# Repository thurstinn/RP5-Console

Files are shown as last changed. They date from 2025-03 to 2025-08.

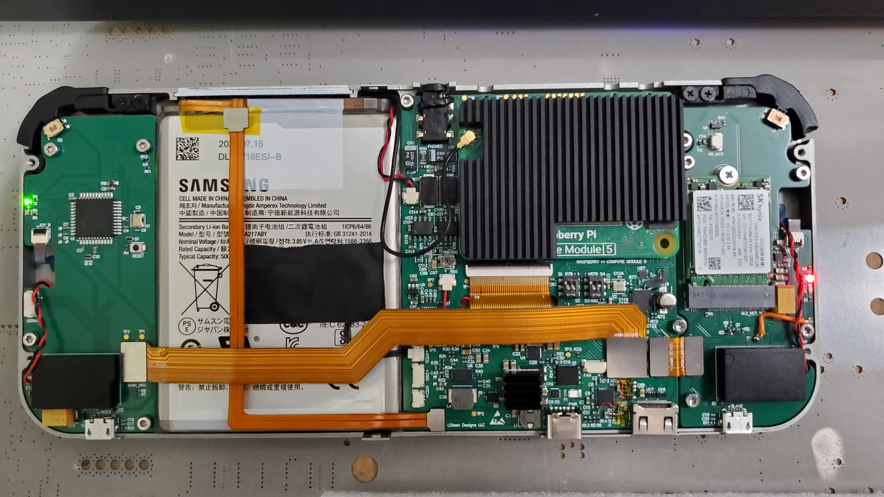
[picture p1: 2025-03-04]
Images/Internal.jpg

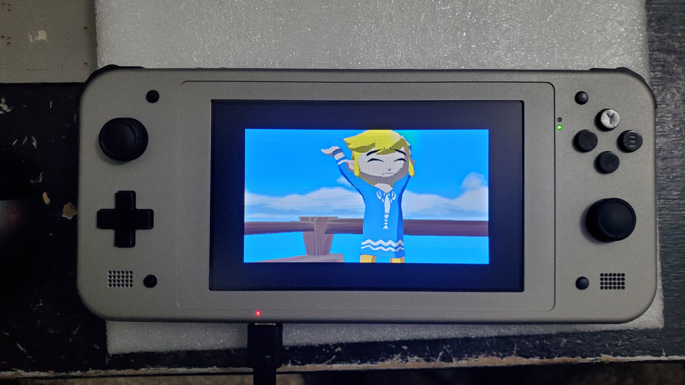
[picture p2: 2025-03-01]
Images/Front2.jpg

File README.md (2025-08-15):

# RP5-Console



This project was inspired by StonedEdge's impressive Retro-Lite-CM4 https://github.com/StonedEdge/Retro-Lite-CM4. I do not use any of their files directly (the exception being their project partner's Ardupad.ino https://github.com/dmcke5/Ardupad), but some of the design choices were influenced by their console.

The process of building this console and setting it up can be complex, expensive, and time consuming. Not for the faint of heart

Assuming you have all the boards assembled and all the parts ready, assembly is pretty straightforward. Use the images as a guide. You will have to extend the speaker wires to reach their connectors. DO NOT GLUE THE BATTERY OR ANYTHING TO THE BACK OF THE SCREEN! I use a large square piece of soft foam double sided taped to the inside of the back cover to compress down on the battery, and by extension the screen, to hold it in place. Tape could also be used. I also chose not to glue or use double sided tape to keep the screen attached to the front cover. I use kapton tape on the outer edges of the screen. Kapton is clean and holds well after compressing it down on a surface. I also used 3mm thick harder foam pieces attched at various points on the back of the main board to softly compress against the back of the screen. This is in an effort to make replacing parts much easier while avoiding damage.

# Setup

Keep battery installed but disconnected until prompted

With the back casing removed and the battery disconnected, place console face down on a soft surface

Set manual power switch to on position (Use dull-ended tweezers)

ATSAMD21E18A and ATMEGA32U4 ICs need USB bootloaders. ATMEGAs Leonardo bootloader can be acquired and flashed using an Arduino Nano in Arduino IDE. ATSAMD21s Adafruit Trinket M0 bootloader can be flashed using a J-Link EDU mini in Microchip Studio. There are online resources for help with this (https://learn.adafruit.com/how-to-program-samd-bootloaders/overview). (I couldn't get Microchip Studio to read the chip on my Windows 11 desktop but it worked on my Windows 10 laptop) You will need to make wire breakouts from the associated connectors for each device. The MPN for the mates of each connector are located in the schematics (SUHR-0XV-S). The MPN of the metal contacts that need crimped on the wires (32-28 awg) for all connector mates is: SSUH-003T-P0.15

Connect the battery

Connect Raspberry Pi 27W USB-C Power Supply (or any USB-C Power Delivery 12V 2A+ capable supply) to USB-C port on the console

Burn the bootloaders

Press the reset buttons on each device

Connect a Micro-USB cable from the slave port (right Micro-USB port with console face down) to PC

Follow the truth table on the Main Board/USB schematic for ATSAMD21 (Switch 1-4 = low, high, low, high) and ATMEGA (Switch 1-4 = high, low, low, high) (low = switch down position and vice-versa)

Use Arduino IDE to flash the included scripts for each device. For ATSAMD21, install and select Adafruit Trinket M0 and double-click reset button to show up as COM Port. For ATMEGA, select Arduino Leonardo and hit the reset button once flashing begins

Follow the instructions in the Ardupad script to calibrate the joysticks

Follow the instructions in the README in the EDID folder

Set manual power switch to off postition

If using an SSD or EMMC, follow the truth table on the Main Board/USB schematic to boot CM5 in rpiboot mode: (Switch 1-4 = low, low, high, low)

Set manual power switch to on position

On PC, install and run Raspberry Pi Imager: https://www.raspberrypi.com/software/

On PC, follow the instructions to install and run rpiboot for CM5 at: https://www.raspberrypi.com/documentation/computers/compute-module.html#set-up-the-host-device

Follow the instructions to install retropie on PI5 OS Lite at: https://github.com/danielfreer/raspberrypi5-retropie-setup (Choose SSD if installed or EMMC as storage unless you have CM5 Lite version. In that case, skip rpiboot and just flash an SD Card)

Set manual power switch to off postition

Follow the truth table on the Main Board/USB schematic for normal operation: (Switch 1-4 = low, low, low, high)

Turn the trimming resistor (R68) just over half way. If turned much more it could damage the speakers

Set manual power switch to on postition and keep it there

Use WinSCP or SSH Terminal to:

Make sure /boot/firmware/config.txt is identical to included config.txt file

Copy Scripts folder to /home/pi/

In SSH Terminal:

Copy service file contents for each file to new files of the same names in /etc/systemd/system/ ex: sudo nano /etc/systemd/system/fan.service

Enable each service: ex: sudo systemctl enable fan.service

Run:

sudo apt remove python3-rpi.gpio

sudo apt-get install python3-rpi-lgpio

sudo apt-get install python3-evdev

sudo nano /var/log/fan.log (write out empty file)

sudo nano /var/log/fan.rpm (write out empty file)

sudo chmod 777 /var/log/fan.log

sudo chmod 777 /var/log/fan.rpm

In (sudo raspi-config) and retropie/audio, set the audio output to USB AUDIO CODEC

In the retropie main menu/sound settings (press start button), the audio card should be default and device should be PCM

sudo reboot

To turn on the console, press and hold the power button for 5 seconds. The power led will turn on (red) and then switch to the activity led (now solid green). To turn off, press and hold the power button for 5 seconds. This will soft shutdown the OS and then turn off the console. If you shutdown the OS via the UI or terminal, you will have to press and hold the power button once the shutdown process has finished to turn off the console

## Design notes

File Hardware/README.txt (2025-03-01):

Files named with Right/Left designate which parts are Right/Left with the console laying facedown, 
as would be during assembly. This was done because while designing I visualized the system this way,
and so I named the parts accordingly to avoid a mix-up. So right is actually left when the console is
facing you like normal and vice-versa.

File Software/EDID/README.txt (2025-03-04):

Program EDID using Arduino Uno or Nano boards:

GND EDID connector pin 1 to Arduino GND
5V EDID connector pin 2 to Arduino 5V
SDA EDID connector pin 3 to Arduino SDA A4
SCL EDID connector pin 4 to Arduino SCL A5 

1. Flash Arduino Uno or Nano board with EDID.ino
3. Unplug Arduino board USB from PC
3. Connect above Arduino board pins to EDID connector on RP5 PCB
4. Move EDID switch to EDID Flash position (down position on attached PCB)
5. Connect Arduino board USB to PC
6. Check Arduino board is connected and open Serial Monitor in Arduino IDE
7. Follow Serial Instructions (Press any key and Enter)
8. If verified successfully, Remove Arduino board USB from PC
9. Move EDID switch back to normal position (up position on attached PCB)

More Info: https://learn.adafruit.com/adafruit-tfp401-hdmi-slash-dvi-decoder-to-40-pin-ttl-display/editing-the-edid

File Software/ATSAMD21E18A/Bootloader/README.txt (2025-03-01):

Follow bootloader programming guide at Adafruit.com:
https://learn.adafruit.com/how-to-program-samd-bootloaders/overview

update-bootloader...uf2 programming not necessary just use .bin file
You can use the circuit python uf2 if you would rather transpile script to circuit python, details are in Adafruit guide.

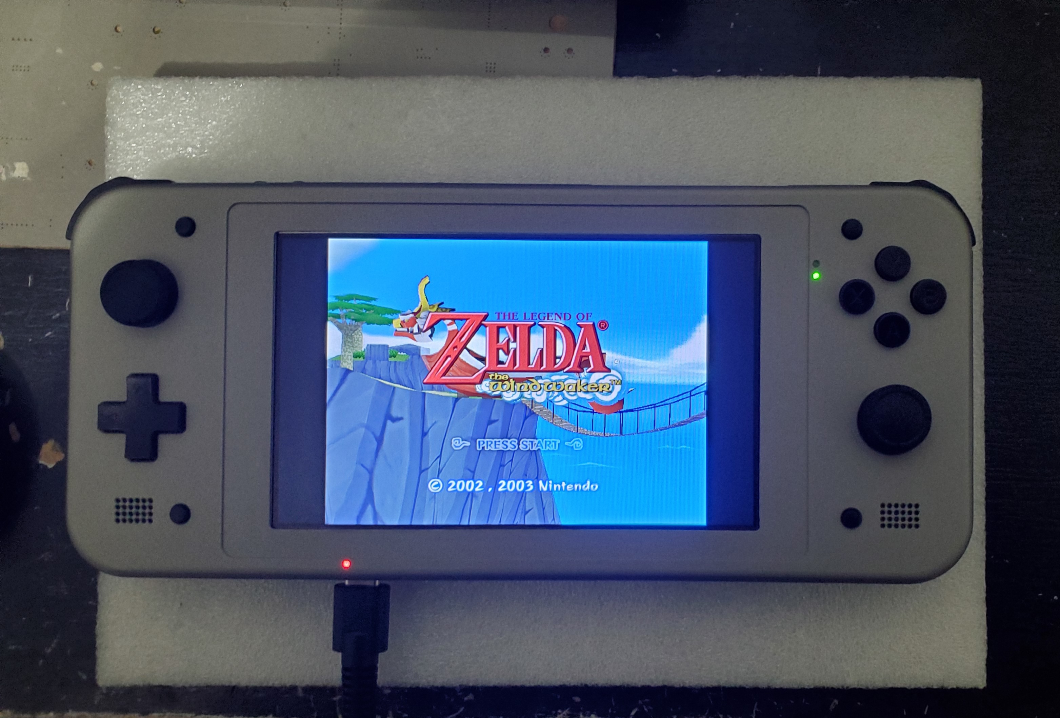
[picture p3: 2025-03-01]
Images/Front1.jpg

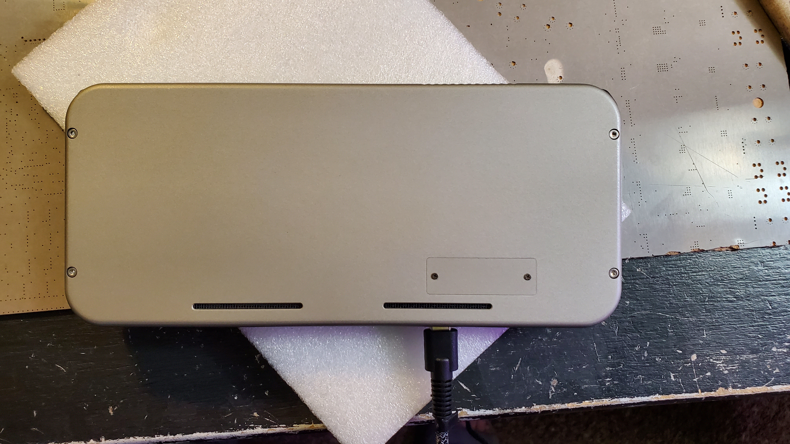
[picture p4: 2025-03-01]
Images/Back.jpg

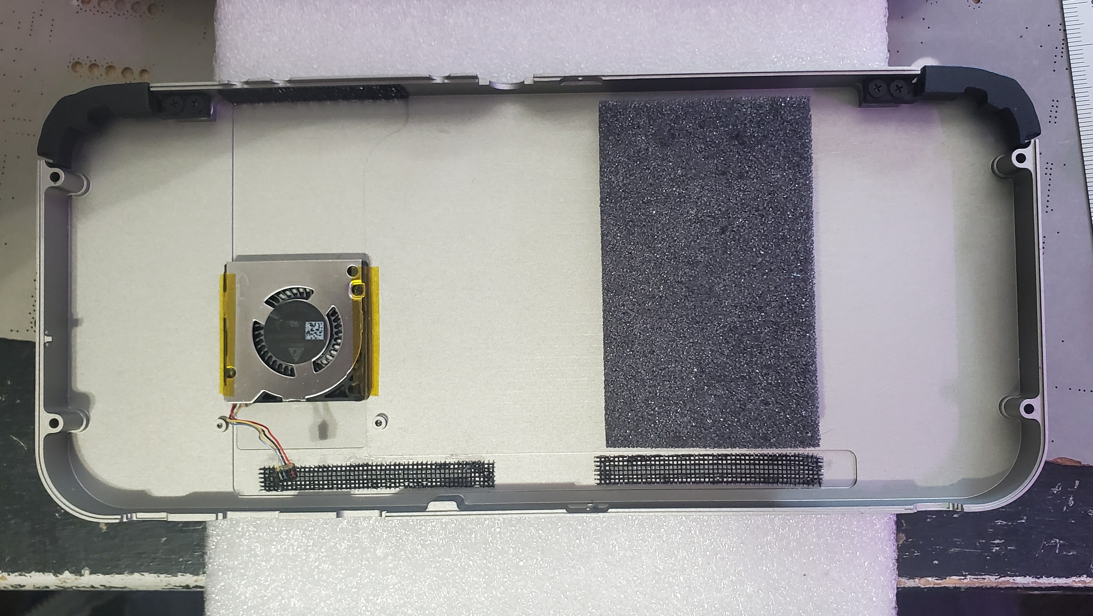
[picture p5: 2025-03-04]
Images/Back_Cover.jpg

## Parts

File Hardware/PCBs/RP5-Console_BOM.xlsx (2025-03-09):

Comment | Size | Designator | Quantity | Manufacturer Part Number | Supplier Part Number | Supplier
Main Board
MPU-6050 |  | AC1 | 1 | MPU-6050 | C24112 | LCSC
47nF | C0402 | C1 | 1 |  |  | LCSC
330pF | C0402 | C2, C12 | 2 |  |  | LCSC
10uF | C0805 | C3, C4, C5, C6, C10, C33, C34, C52, C53, C56, C95, C103, C111, C118 | 14 |  |  | LCSC
4.7uF | C0603 | C7, C39, C91 | 3 |  |  | LCSC
0.01uF | C0402 | C8, C9 | 2 |  |  | LCSC
2.2uF | C0603 | C11 | 1 |  |  | LCSC
10uF | C0603 | C13, C17, C18, C24, C25, C48, C59, C60, C87, C88, C116 | 11 |  |  | LCSC
0.1uF | C0402 | C14, C16, C20, C21, C29, C31, C35, C37, C38, C42, C43, C47, C49, C50, C61, C63, C71, C72, C73, C74, C75, C76, C77, C78, C79, C80, C81, C82, C84, C85, C89, C90, C92, C93, C101, C105, C121, C125, C126, C127, C128, C132, C133, C134, C135 | 45 |  |  | LCSC
0.001uF | C0402 | C15 | 1 |  |  | LCSC
2.2uF | C0402 | C19 | 1 |  |  | LCSC
4.7uF | C0805 | C22 | 1 |  |  | LCSC
4.7uF | C0805 | C23, C44 | 2 |  |  | LCSC
1uF | C0402 | C26, C41 | 2 |  |  | LCSC
47uF | C0805 | C27, C28, C45, C46 | 4 |  |  | LCSC
10pF | C0402 | C30, C107, C108, C130, C131 | 5 |  |  | LCSC
0.22uF | C0402 | C32 | 1 |  |  | LCSC
100pF | C0402 | C36 | 1 |  |  | LCSC
4700pF | C0402 | C40 | 1 |  |  | LCSC
0.1uF | C0402 | C51, C68, C69, C70, C83 | 5 |  |  | LCSC
47uF |  | C54 | 1 | TLJR476M010R3200 | 581-TLJR476M10R3200 | Mouser
1uF | C0603 | C55, C57, C58, C62, C94, C104, C106, C119, C120, C123, C124, C129 | 12 |  |  | LCSC
22uF |  | C64, C65, C66, C67 | 4 | TACR226K006XTA | 581-TACR226K006X | Mouser
2.2nF | C0402 | C86 | 1 |  |  | LCSC
220uF |  | C96, C97 | 2 | TR3C227K6R3C0225 | 74-TR3C227K6R3C0225 | Mouser
100uF |  | C98, C109 | 2 | EEF-CX0J101R | 667-EEF-CX0J101R | Mouser
33nF | C0603 | C99, C110 | 2 |  |  | LCSC
47uF | C0603 | C100, C102 | 2 |  |  | LCSC
10uF | C0402 | C112, C113, C114, C115, C117 | 5 |  |  | LCSC
10uF |  | C122 | 1 | UZG1C100MCL1GB | 493-10050-1-ND | Digikey
PWR |  | CN1 | 1 | U262-061N-4BVC11 | C2764612 | LCSC
BAT | CN2 | https://www.aliexpress.us/item/3256805377191711.html | 1 |  |  | Aliexpress
NTC0 |  | CN3 | 1 | SM02B-SURS-TF(LF)(SN) | C566239 | LCSC
FAN |  | CN4 | 1 | SM04B-SURS-TF(LF)(SN) | 455-3589-1-ND | Digikey
SWD |  | CN5 | 1 | SM04B-SURS-TF(LF)(SN) | 455-3589-1-ND | Digikey
DISPLAY |  | CN6 | 1 | F3311A7H121040E200 | 649-311A7H121040E200 | Mouser
EDID |  | CN7 | 1 | SM04B-SURS-TF(LF)(SN) | 455-3589-1-ND | Digikey
NTC1 |  | CN8 | 1 | SM02B-SURS-TF(LF)(SN) | 455-3589-1-ND | Digikey
uSD |  | CN9 | 1 | MSD-9-A | 179-MSD-9-A | Mouser
HDMI |  | CN10 | 1 | 685119136923 | 710-685119136923 | Mouser
PHONES |  | CN11 | 1 | SJ-43615TS-SMT-TR | 490-SJ43615TSSMTTR | Mouser
SPK_L |  | CN12 | 1 | SM02B-SURS-TF(LF)(SN) | C566239 | LCSC
SPK_R |  | CN13 | 1 | SM02B-SURS-TF(LF)(SN) | C566239 | LCSC
LFT_BRD |  | CN14 | 1 | BM20B(0.8)-40DS-0.4V(51) | 798-BM20B0840DS04V51 | Mouser
RT_BRD |  | CN15 | 1 | BM20B(0.8)-40DS-0.4V(51) | 798-BM20B0840DS04V51 | Mouser
PMEG045V100EIPE-QZ |  | D1 | 1 | PMEG045V100EIPE-QZ | 771-PMEG045V100EIPEZ | Mouser
PMEG3030EXEX |  | D2 | 1 | PMEG3030EXEX | 771-PMEG3030EXEX | Mouser
TVS3300DRVR |  | D3 | 1 | TVS3300DRVR | 595-TVS3300DRVR | Mouser
RB050LAM-40TR |  | D4 | 1 | RB050LAM-40TR | 755-RB050LAM-40TR | Mouser
GBLC08C-N |  | D5 | 1 | GBLC08C-N | C314256 | LCSC
1206SFF700F/32-2 |  | F1 | 1 | 1206SFF700F/32-2 | 650-1206SFF700F/32-2 | Mouser
220Ω |  | FB1, FB2, FB3, FB4, FB5, FB6, FB7, FB10, FB11, FB12 | 10 | BLM18SG221TZ1D | 81-BLM18SG221TZ1D | Mouser
NFZ15SF102SN10D |  | FB8, FB9 | 2 | NFZ15SF102SN10D | 81-NFZ15SF102SN10D | Mouser
SPM5030T-2R2M-HZ |  | L1 | 1 | SPM5030T-2R2M-HZ | 810-SPM5030T-2R2M-HZ | Mouser
XFL4020-102MEC |  | L2 | 1 | XFL4020-102MEC | 994-XFL4020-102MEC | Mouser
IHLP2020BZER100M11 |  | L3 | 1 | IHLP2020BZER100M11 | C844984 | LCSC
ETQ-P4M4R7YFP |  | L4 | 1 | ETQ-P4M4R7YFP | 667-ETQ-P4M4R7YFP | Mouser
LB |  | LED1 | 1 | 19-217UYOC/S3112/TR8 | C264473 | LCSC
STAT |  | LED2 | 1 | 19-217/R6C-AL1M2VY/3T | 1080-1585-6-ND | Digikey
RGB |  | LED3 | 1 | 3341 | 485-3341 | Mouser
IND |  | LED4 | 1 | 19-217/R6C-AL1M2VY/3T | 1080-1585-6-ND | Digikey
SUSP |  | LED5 | 1 | 19-217/R6C-AL1M2VY/3T | 1080-1585-6-ND | Digikey
HP8KA1TB |  | Q1 | 1 | HP8KA1TB | 755-HP8KA1TB | Mouser
RQ1E070RPTR |  | Q2 | 1 | RQ1E070RPTR | 755-RQ1E070RPTR | Mouser
SS8050-G |  | Q3 | 1 | SS8050-G | 750-SS8050-G | Mouser
STL3N10F7 |  | Q4, Q5, Q6 | 3 | STL3N10F7 | 511-STL3N10F7 | Mouser
DDTA143TCA-7-F |  | Q7 | 1 | DDTA143TCA-F | 621-DDTA143TCA-F | Mouser
10k | R0402 | R1, R3, R4, R12, R13, R14, R22, R24, R30, R45, R48, R49, R51, R52, R58, R77, R78, R81, R82, R83, R84 | 21 |  |  | LCSC
20 | R0402 | R2 | 1 |  |  | LCSC
NC | R0402 | R5, R47, R50 | 3 |  |  | LCSC
180k | R0402 | R6, R7, R8 | 3 |  |  | LCSC
1M | R0402 | R9, R71, R73 | 3 |  |  | LCSC
5.3k | R0402 | R10 | 1 |  |  | LCSC
20k | R0402 | R11, R20, R53, R54 | 4 |  |  | LCSC
0R | R0402 | R15, R44 | 2 |  |  | LCSC
39k | R0402 | R16, R17, R18 | 3 |  |  | LCSC
30.9k | R0402 | R19, R37 | 2 |  |  | LCSC
1k | R0402 | R21, R26, R28, R38, R39, R72 | 6 |  |  | LCSC
10k | R0402 | R23, R27, R32 | 3 |  |  | LCSC
1.15M | R0402 | R25 | 1 |  |  | LCSC
205k | R0402 | R29 | 1 |  |  | LCSC
5R 1W | R2512 | R31 | 1 | HoAR2512-1W-5R-0.1%-TCR25 | C5123609 | LCSC
10R | R0402 | R33, R41 | 2 |  |  | LCSC
100k | R0402 | R34, R63, R66, R74, R75 | 5 |  |  | LCSC
150k | R0402 | R35 | 1 |  |  | LCSC
15k | R0402 | R36 | 1 |  |  | LCSC
10m 1W | R1206 | R40 | 1 |  |  | LCSC
330R | R0402 | R42 | 1 |  |  | LCSC
49.9K | R0402 | R43 | 1 |  |  | LCSC
1.5k | R0402 | R46, R64, R65, R67 | 4 |  |  | LCSC
4.7k | R0402 | R55, R56, R76 | 3 |  |  | LCSC
12k | R0402 | R57 | 1 |  |  | LCSC
5R1 | R0805 | R59, R60 | 2 |  |  | LCSC
150R | R0402 | R61, R62 | 2 |  |  | LCSC
TC33X-2-103E |  | R68 | 1 | TC33X-2-103E | 652-TC33X-2-103E | Mouser
22R | R0402 | R69, R70 | 2 |  |  | LCSC
47k | R0402 | R79 | 1 |  |  | LCSC
649R | R0402 | R80 | 1 |  |  | LCSC
3R | R0402 | RN1, RN2, RN3, RN4, RN5, RN6, RN7 | 7 | YC124-JR-0733RL | 603-YC124-JR-0733RL | Mouser
PWR |  | SW1 | 1 | APTCLGTVTR | 642-APTCLGTVTR | Mouser
PWR |  | SW2 | 1 | MK-11C04-G013 | C778185 | LCSC
RESETm |  | SW3 | 1 | B3U-1000P | 653-B3U-1000P | Mouser
EDID_FLASH |  | SW4 | 1 | MK-11C04-G013 | C778185 | LCSC
VOL+ |  | SW5 | 1 | APTCLGTVTR | 642-APTCLGTVTR | Mouser
VOL- |  | SW6 | 1 | APTCLGTVTR | 642-APTCLGTVTR | Mouser
USB_SW1/SW2 |  | SW7 | 1 | CAS-D20A1 | 229-CAS-D20A1 | Mouser
USB_SW3/SW4 |  | SW8 | 1 | CAS-D20A1 | 229-CAS-D20A1 | Mouser
BQ25303JRTER |  | U1 | 1 | BQ25303JRTER | 595-BQ25303JRTER | Mouser
XC6136N35BNR-G |  | U2 | 1 | XC6136N35BNR-G | 865-XC6136N35BNR-G | Mouser
TPS25730SRSMR |  | U3 | 1 | TPS25730SRSMR | 595-TPS25730SRSMR | Mouser
TPS63060DSCR |  | U4 | 1 | TPS63060DSCR | 595-TPS63060DSCR | Mouser
TPS61165DRVR |  | U5 | 1 | TPS61165DRVR | 595-TPS61165DRVR | Mouser
TPS552892QWRYQRQ1 |  | U6 | 1 | TPS552892QWRYQRQ1 | 595-PS552892QWRYQRQ1 | Mouser
ATSAMD21E18A-MUT |  | U7 | 1 | ATSAMD21E18A-MUT | 556-ATSAMD21E18A-MUT | Mouser
TLV75733PDRVR |  | U8 | 1 | TLV75733PDRVR | 595-TLV75733PDRVR | Mouser
ME6211C33M5G-N |  | U9 | 1 | ME6211C33M5G-N | C82942 | LCSC
TPS7A4700RGWR |  | U10 | 1 | TPS7A4700RGWR | 595-TPS7A4700RGWR | Mouser
TFP401APZPR |  | U11 | 1 | TFP401APZPR | 595-TFP401APZPR | Mouser
24LC02BT-I/OT |  | U12 | 1 | 24LC02BT-I/OT | 579-24LC02BT-I/OT | Mouser
CM5102008 |  | U13 | 1 | COMPUTE MODULE 5 | Wireless/ No MMC /8Gb | Rasberry Pi
MCP3004-I/ST |  | U14 | 1 | MCP3004-I/ST | 579-MCP3004-I/ST | Mouser
RT9742GGJ5 |  | U15 | 1 | RT9742GGJ5 | 835-RT9742GGJ5 | Mouser
ESD224DQAR |  | U16, U18 | 2 | ESD224DQAR | 595-ESD224DQAR | Mouser
TPD3S014TDBVRQ1 |  | U17 | 1 | TPD3S014TDBVRQ1 | 595-TPD3S014TDBVRQ1 | Mouser
SN74LVC1G08DBVT |  | U19 | 1 | SN74LVC1G08DBVT | 595-SN74LVC1G08DBVT | Mouser
LM4865MX/NOPB |  | U20, U22 | 2 | LM4865MX/NOPB | 926-LM4865MX/NOPB | Mouser
PCM2903CDB |  | U21 | 1 | PCM2903CDB | 595-PCM2903CDB | Mouser
CY7C65632-28LTXC |  | U23 | 1 | CY7C65632-28LTXC | 727-CY7C65632-28LTXC | Mouser
USB_SW1_TS3USB221ARSER |  | U24 | 1 | TS3USB221ARSER | 595-TS3USB221ARSER | Mouser
USB_SW4_TS3USB221ARSER |  | U25 | 1 | TS3USB221ARSER | 595-TS3USB221ARSER | Mouser
USB_SW2_TS3USB221ARSER |  | U26 | 1 | TS3USB221ARSER | 595-TS3USB221ARSER | Mouser
USB_SW3_TS3USB221ARSER |  | U27 | 1 | TS3USB221ARSER | 595-TS3USB221ARSER | Mouser
12MHz |  | X1, X2 | 2 | ABM8G-12.000MHZ-B4Y-T | 815-ABM8G-12-B4Y-T | Mouser
CM5 CONNECTORS |  | CN0 | 2 | 10164227-1001A1RLF | 649-01642271001A1RLF | Mouser
Total: | 315
RightBoard
0.1uF | C0402 | C1, C2, C3, C4, C7, C8, C9, C10, C11, C13, C14, C16, C17, C19, C21 | 15 |  |  | LCSC
10uF | C0805 | C5, C6, C12, C18 | 4 |  |  | LCSC
150uF |  | C15 | 1 | TPSD157K016S0125 | 581-TPSD157K016S0125 | Mouser
0.001uF | C0402 | C20 | 1 |  |  | LCSC
M.2_KEY_M |  | CN1 | 1 | 1-2199119-6 | 571-1-2199119-6 | Mouser
JOY_L |  | CN2 | 1 | 503480-0540 | 538-503480-0540 | Mouser
MAIN_BRD |  | CN3 | 1 | BM20B(0.8)-40DS-0.4V(51) | 798-BM20B0840DS04V51 | Mouser
SLAVE |  | CN4 | 1 | 105017-0001 | 538-105017-0001 | Mouser
VIB_MOT |  | CN5 | 1 | SM02B-SURS-TF(LF)(SN) | C566239 | LCSC
TPD2E009DRTR |  | D1 | 1 | TPD2E009DRTR | 595-TPD2E009DRTR | Mouser
1SS400T1G |  | D2, D3, D4 | 3 | 1SS400T1G | 863-1SS400T1G | Mouser
ACT |  | LED1 | 1 | 19-219/GHC-YR2T1B5Y/3T | C2994781 | LCSC
PWR |  | LED2 | 1 | 19-213/R6C-AP1Q2B/5T | C2984264 | LCSC
DMG1012T-7 |  | Q1, Q2, Q3 | 3 | DMG1012T-7 | 621-DMG1012T-7 | Mouser
SS8050-G |  | Q4 | 1 | SS8050-G | 750-SS8050-G | Mouser
1k | R0402 | R1, R6, R15 | 3 |  |  | LCSC
2.2k | R0402 | R2, R5 | 2 |  |  | LCSC
10k | R0402 | R3, R9, R10, R13, R14, R16 | 6 |  |  | LCSC
33R | R0402 | R4, R8 | 2 |  |  | LCSC
1R | R0402 | R7 | 1 |  |  | LCSC
1M | R0402 | R11 | 1 |  |  | LCSC
100k | R0402 | R12 | 1 |  |  | LCSC
L1 |  | SW1 | 1 | APTCLGTVTR | 642-APTCLGTVTR | Mouser
L2 |  | SW2 | 1 | APTCLGTVTR | 642-APTCLGTVTR | Mouser
SELECT |  | SW3 | 1 | EVQ-Q2B03W | 667-EVQ-Q2B03W | Mouser
HK |  | SW6 | 1 | EVQ-Q2B03W | 667-EVQ-Q2B03W | Mouser
AP22653FDZ-7 |  | U1 | 1 | AP22653FDZ-7 | 621-AP22653FDZ-7 | Mouser
74LVC1G3157FZ4-7 |  | U2 | 1 | 74LVC1G3157FZ4-7 | 621-74LVC1G3157FZ4-7 | Mouser
ECS-327KE-TR |  | X1 | 1 | ECS-327KE-TR | 520-ECS-327KE-TR | Mouser
Total: | 59
Left Board
0.1uF | C0402 | C1, C3, C4, C7, C9, C12, C13, C14, C16 | 9 |  |  | LCSC
1uF | C0603 | C2, C8, C10 | 3 |  |  | LCSC
10pF | C0402 | C5, C6 | 2 |  |  | LCSC
150uF |  | C11 | 1 |  | 581-TPSD157K016S0125 | Mouser
10uF | C0805 | C15 | 1 |  |  | LCSC
0.001uF | C0402 | C17 | 1 |  |  | LCSC
JOY_R |  | CN1 | 1 | 503480-0540 | 538-503480-0540 | Mouser
SERIAL |  | CN2 | 1 | SM05B-SURS-TF(LF)(SN) | 455-3590-1-ND | Digikey
HOST |  | CN3 | 1 | 105017-0001 | 538-105017-0001 | Mouser
MAIN_BRD |  | CN4 | 1 | BM20B(0.8)-40DS-0.4V(51) | 798-BM20B0840DS04V51 | Mouser
1SS400T1G |  | D1 | 1 | 1SS400T1G | 863-1SS400T1G | Mouser
TPD2E009DRTR |  | D2 | 1 | TPD2E009DRTR | 595-TPD2E009DRTR | Mouser
GBLC08C-N |  | D3 | 1 | GBLC08C-N | C314256 | LCSC
30Ω |  | FB1 | 1 | MH2029-300Y | 652-MH2029-300Y | Mouser
TX |  | LED1 | 1 | SM0402GC | 749-SM0402GC | Mouser
RX |  | LED2 | 1 | SM0402RC | 749-SM0402RC | Mouser
ACT |  | LED3 | 1 | 19-219/GHC-YR2T1B5Y/3T | C2994781 | LCSC
PWR |  | LED4 | 1 | 19-213/R6C-AP1Q2B/5T | C2984264 | LCSC
1M | R0402 | R1, R10 | 2 |  |  | LCSC
22R | R0402 | R2, R3 | 2 |  |  | LCSC
10k | R0402 | R4, R7 | 2 |  |  | LCSC
1k | R0402 | R5, R6, R11, R12 | 4 |  |  | LCSC
100k | R0402 | R8 | 1 |  |  | LCSC
49.9k | R0402 | R9 | 1 |  |  | LCSC
RESET |  | SW2 | 1 | B3U-1000P | 653-B3U-1000P | Mouser
R1 |  | SW3 | 1 | APTCLGTVTR | 642-APTCLGTVTR | Mouser
SYS |  | SW4 | 1 | EVQ-Q2B03W | 667-EVQ-Q2B03W | Mouser
START |  | SW7 | 1 | EVQ-Q2B03W | 667-EVQ-Q2B03W | Mouser
R2 |  | SW8 | 1 | APTCLGTVTR | 642-APTCLGTVTR | Mouser
ATmega32U4-AU |  | U1 | 1 | ATMEGA32U4-AU | 556-ATMEGA32U4-AU | Mouser
AP22652FDZ-7 |  | U2 | 1 | AP22652FDZ-7 | 621-AP22652FDZ-7 | Mouser
74LVC1G07GX4Z |  | U3 | 1 | 74LVC1G07GX4Z | 771-74LVC1G07GX4Z | Mouser
16MHz |  | X1 | 1 | ABM8G-16.000MHZ-B4Y-T | 815-ABM8G-16-B4Y-T | Mouser
Total: | 50
Right FPC
RT_BRD |  | CN1 | 1 | BM20B(0.8)-40DP-0.4V(53) | 798-BM20B0840DP04V53 | Mouser
MAIN_BRD |  | CN2 | 1 | BM20B(0.8)-40DP-0.4V(53) | 798-BM20B0840DP04V53 | Mouser
Left FPC
MAIN_BRD |  | CN1 | 1 | BM20B(0.8)-40DP-0.4V(53) | 798-BM20B0840DP04V53 | Mouser
LFT_BRD |  | CN2 | 1 | BM20B(0.8)-40DP-0.4V(53) | 798-BM20B0840DP04V53 | Mouser
Battery FPC
Comment | Designator | Supplier Link |  |  |  | Supplier
BAT | CN1 | https://www.aliexpress.us/item/3256805377191711.html | 1 |  |  | Aliexpress
BRD | CN2 | https://www.aliexpress.us/item/3256805377191711.html | 1 |  |  | Aliexpress
Grand Total SMD: | 430
Other Parts
Connector Mate |  |  | 10 | SUHR-02V-S | 455-3563-ND | Digikey
Connector Mate |  |  | 5 | SUHR-04V-S | C398470 | LCSC
Connector Mate |  |  | 5 | SUHR-05V-S | 455-3568-ND | Digikey
Connector Contact |  |  | 100 | SSUH-003T-P0.15 | C567084 | LCSC
Programmer |  | J-Link Debugger for Programming SAMD21E18A bootloader | 1 | 8.08.91 | 943-8.08.91 | Mouser
J-Link Breakout |  |  | 1 | 2743 | 485-2743 | Mouser
Antenna |  |  | 1 | ANT-W63-FPC-LV100UF | 712-ANTW63FPCLV100UF | Mouser
EMI Shield |  |  | 1 | IFL10M-200ND300X200 | 445-180349-ND | Digikey
VIB Motor |  |  | 1 | 1638 | 2183-1638-ND | Digikey
Fan |  |  | 1 | KDB0305HA3-00 | 603-2069-ND | Digikey
Power Supply |  | USB-C PD 12V-2A+ | 1 | Raspberry Pi 5 Power Supply (27W USB-C) |  | CanaKit
Batery |  | Samsung 3.85V 5.8Ah | 1 | https://www.amazon.com/dp/B09NW3K27B?ref=ppx_yo2ov_dt_b_fed_asin_title | EB-BA217ABY | Amazon
SSD |  | M.2 NVMe Key M | 1 | https://www.amazon.com/dp/B0BZJ3J7QZ/?coliid=IACFKLGJOJ7E4&colid=27M5JZWB9CYK8 |  | Amazon
Crimper |  | 32 Awg | 1 | https://www.amazon.com/dp/B002AVVO7K?ref=ppx_yo2ov_dt_b_product_details&th=1 |  | Amazon
Light Pipes |  | PLPC1-100(2.5mm) PLPC1-125(3.2mm) PLPC1-188(4.8mm) PLPC1-250(6.4mm) (Cut to Size) | 5 |  |  | Mouser
Fan Vent Screen |  | Cut to size and Paint black if desired | 1 | RMF-092-T | RPC3203-ND | Digikey
Switch Lite Button Set |  | https://www.amazon.com/dp/B0B2VFTHGX?ref=ppx_yo2ov_dt_b_fed_asin_title&th=1 | 5 | Cut notches according to Front Cover model |  | Amazon
Rubber Conductive Pads |  | https://www.amazon.com/dp/B09LM9MVLM?ref=ppx_yo2ov_dt_b_fed_asin_title | 2 | Lightly glue in place on boards |  | Amazon
Joycon Joysticks |  | https://www.amazon.com/dp/B07MRJ12HX?ref=ppx_yo2ov_dt_b_fed_asin_title | 1 |  |  | Amazon
Screws M2 X 12mm |  | https://www.amazon.com/dp/B094NT2PMX?ref=ppx_yo2ov_dt_b_fed_asin_title&th=1 | 4 |  |  | Amazon
Screws M2 X 5mm |  | https://www.amazon.com/dp/B06XW8MMQW?ref=ppx_yo2ov_dt_b_fed_asin_title | 19 |  |  | Amazon
Screws M1.6 X 3mm |  | https://www.amazon.com/dp/B0CWH1WVJJ?ref_=ppx_hzod_title_dt_b_fed_asin_title_0_0&th=1 | 4 |  |  | Amazon
Screws M1.4 X 2mm |  | https://www.amazon.com/uxcell-M1-4-0-3-Stainless-Furniture-Connection/dp/B0DRGWJ8V6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 | 4 |  |  | Amazon

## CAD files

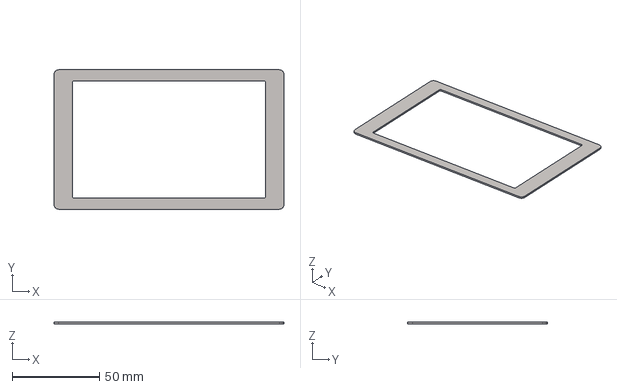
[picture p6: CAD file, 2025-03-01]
Hardware/3D CAD/CNC Acrylic/Bezel.step
132.0 x 80.1 x 1.00 mm

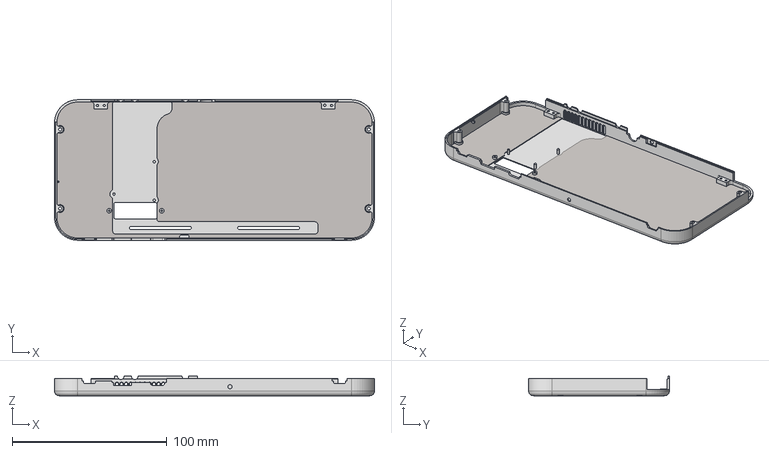
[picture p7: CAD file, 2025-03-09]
Hardware/3D CAD/CNC Aluminum/Back_Cover.step
207.0 x 91.0 x 12.6 mm

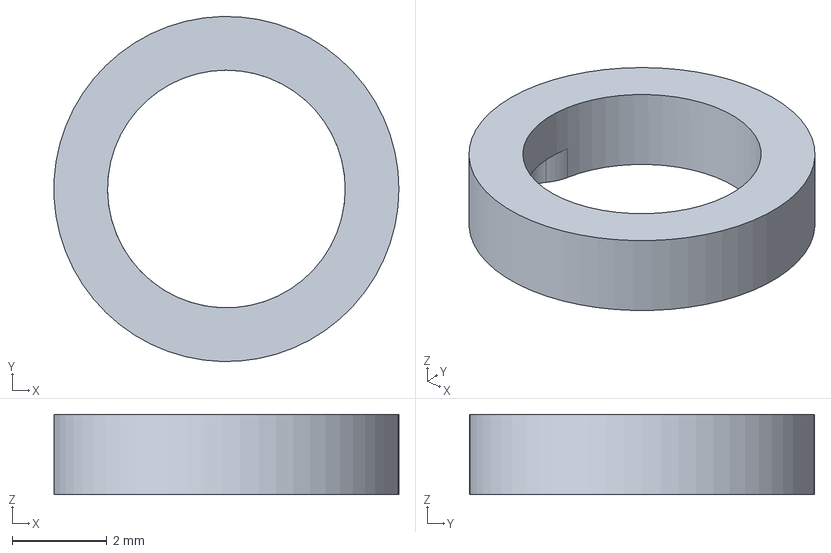
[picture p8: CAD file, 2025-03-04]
Hardware/3D CAD/MJF Nylon/Phones_Jack_Ring.step
7.28 x 7.29 x 1.70 mm

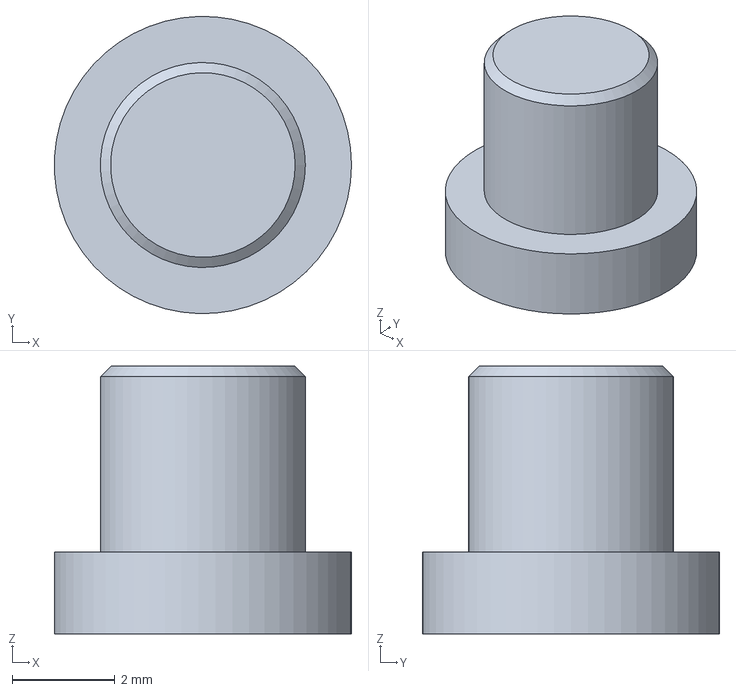
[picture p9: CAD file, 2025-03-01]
Hardware/3D CAD/SLA Resin/Front_SYS_Buttons.step
5.80 x 5.80 x 5.22 mm

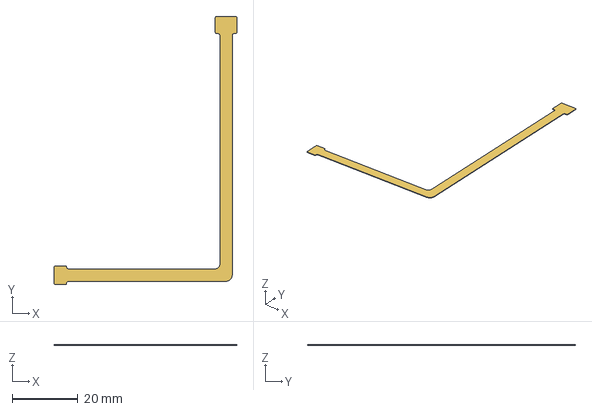
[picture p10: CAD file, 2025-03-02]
Hardware/PCBs/3D Models/Battery_FPC.step
55.7 x 81.8 x 0.195 mm

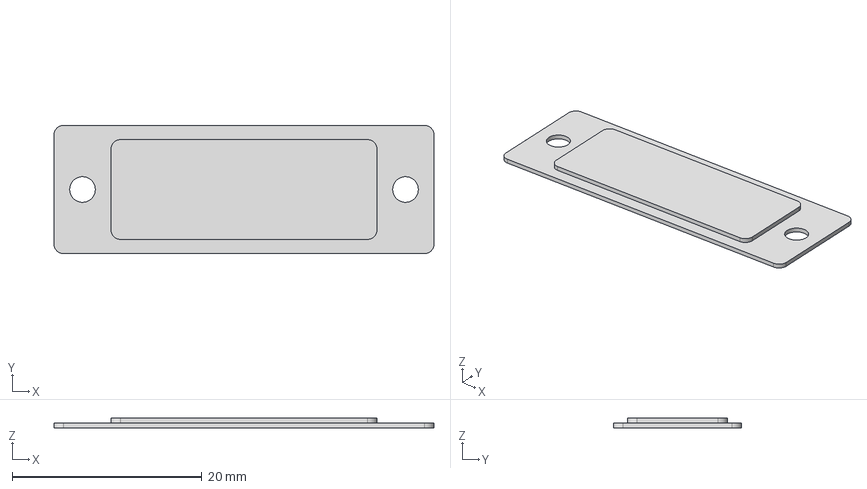
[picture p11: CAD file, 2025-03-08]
Hardware/3D CAD/CNC Aluminum/Fan_CN_Cover.step
40.0 x 13.5 x 1.00 mm

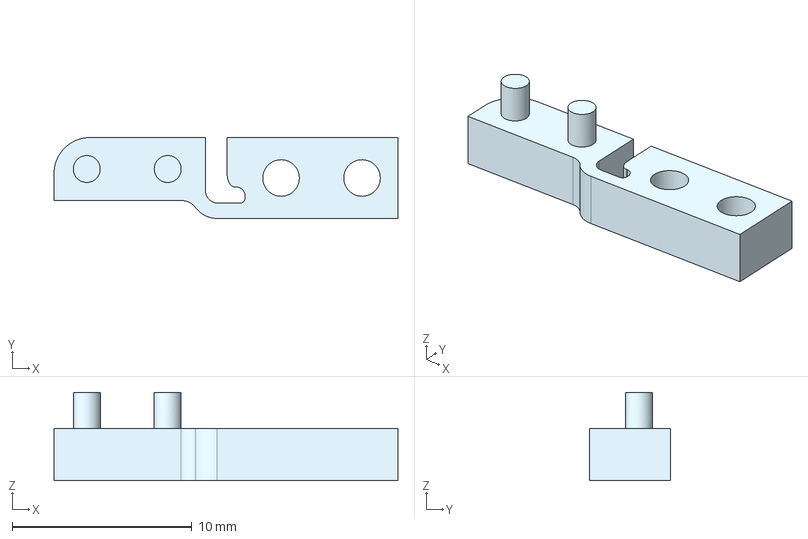
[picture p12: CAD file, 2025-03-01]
Hardware/3D CAD/MJF Nylon/Right_Spring.step
19.1 x 4.50 x 4.90 mm

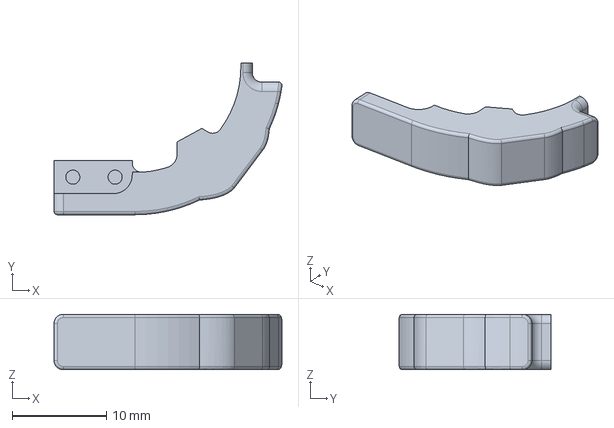
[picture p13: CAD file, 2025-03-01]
Hardware/3D CAD/SLA Resin/Right_Trigger.step
24.2 x 16.1 x 5.90 mm

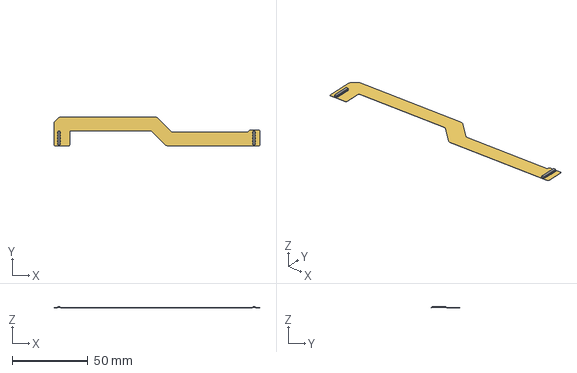
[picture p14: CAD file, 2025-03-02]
Hardware/PCBs/3D Models/Left_FPC.step
135.7 x 18.9 x 0.964 mm

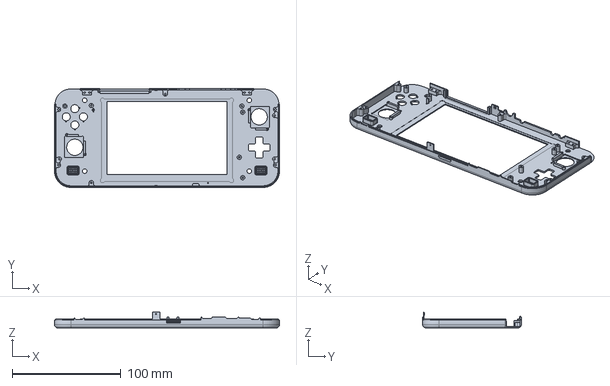
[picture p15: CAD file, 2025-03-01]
Hardware/3D CAD/CNC Aluminum/Front_Cover.step
207.0 x 91.0 x 14.6 mm

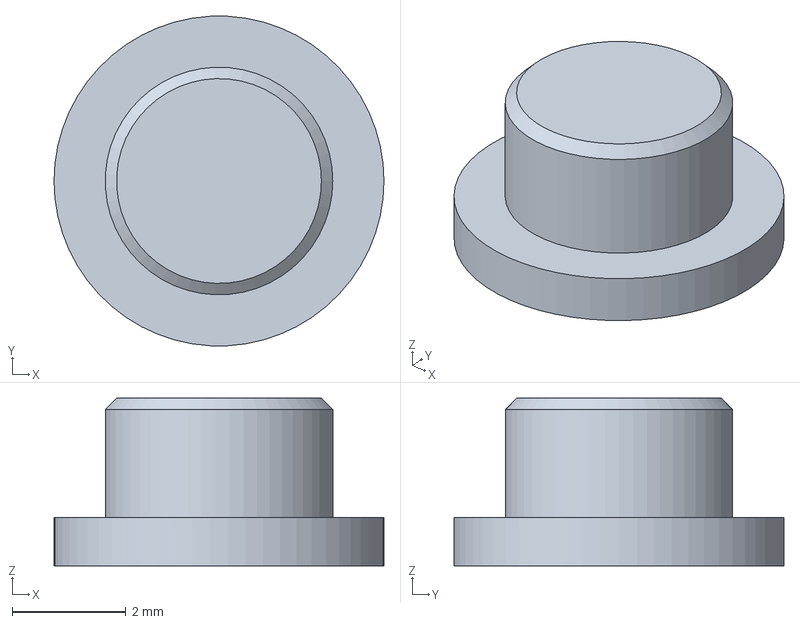
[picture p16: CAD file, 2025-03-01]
Hardware/3D CAD/SLA Resin/Top_Buttons.step
5.80 x 5.79 x 2.95 mm

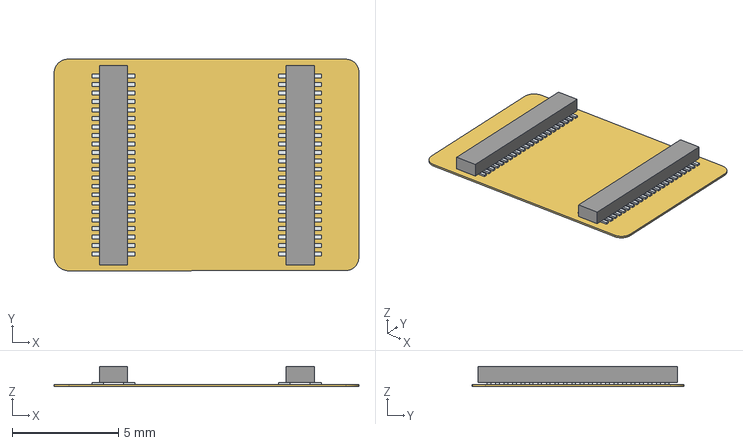
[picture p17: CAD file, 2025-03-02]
Hardware/PCBs/3D Models/Right_FPC.step
14.4 x 9.98 x 0.964 mm

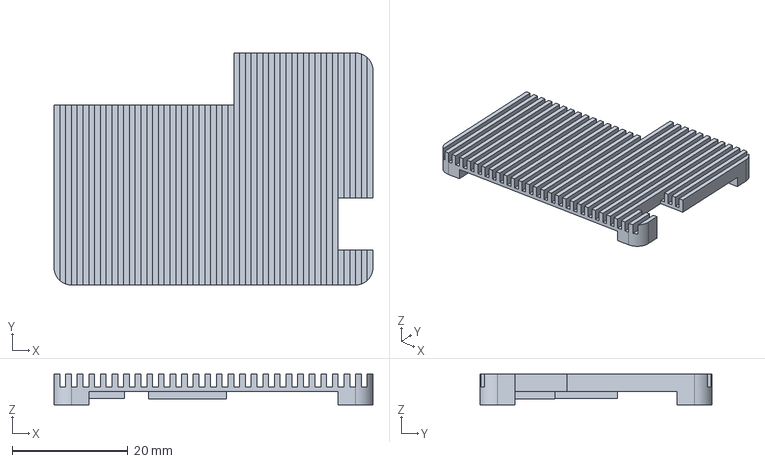
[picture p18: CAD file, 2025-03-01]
Hardware/3D CAD/CNC Aluminum/CM5_Heatsink.step
55.0 x 40.0 x 5.30 mm

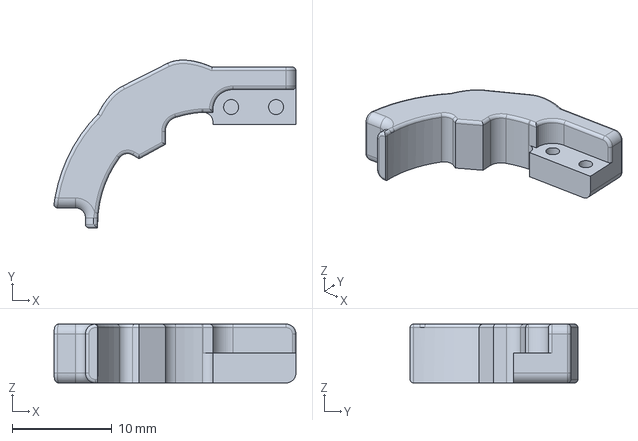
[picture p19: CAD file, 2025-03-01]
Hardware/3D CAD/SLA Resin/Right_Shoulder.step
24.2 x 16.8 x 5.90 mm

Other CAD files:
Hardware/3D CAD/MJF Nylon/Left_Spring.step
Hardware/3D CAD/SLA Resin/Left_Trigger.step
Hardware/3D CAD/SLA Resin/Left_Shoulder.step
Hardware/3D CAD/SLA Resin/Ant_Cover.step

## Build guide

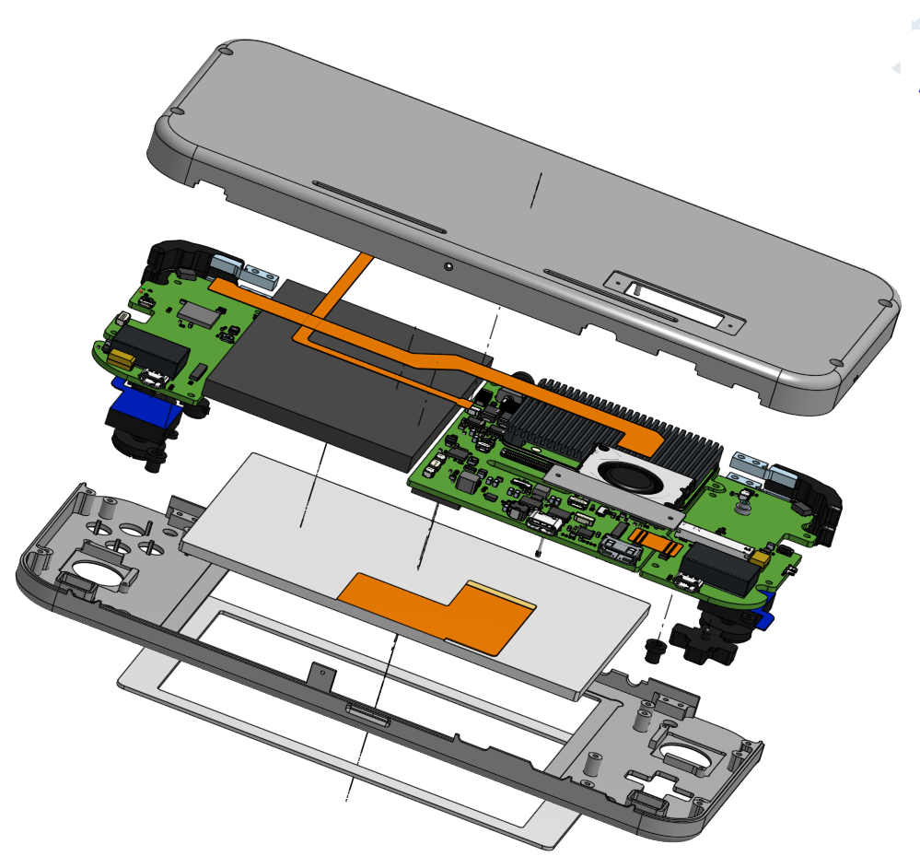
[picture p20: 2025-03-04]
Images/RP5_Assembly.png

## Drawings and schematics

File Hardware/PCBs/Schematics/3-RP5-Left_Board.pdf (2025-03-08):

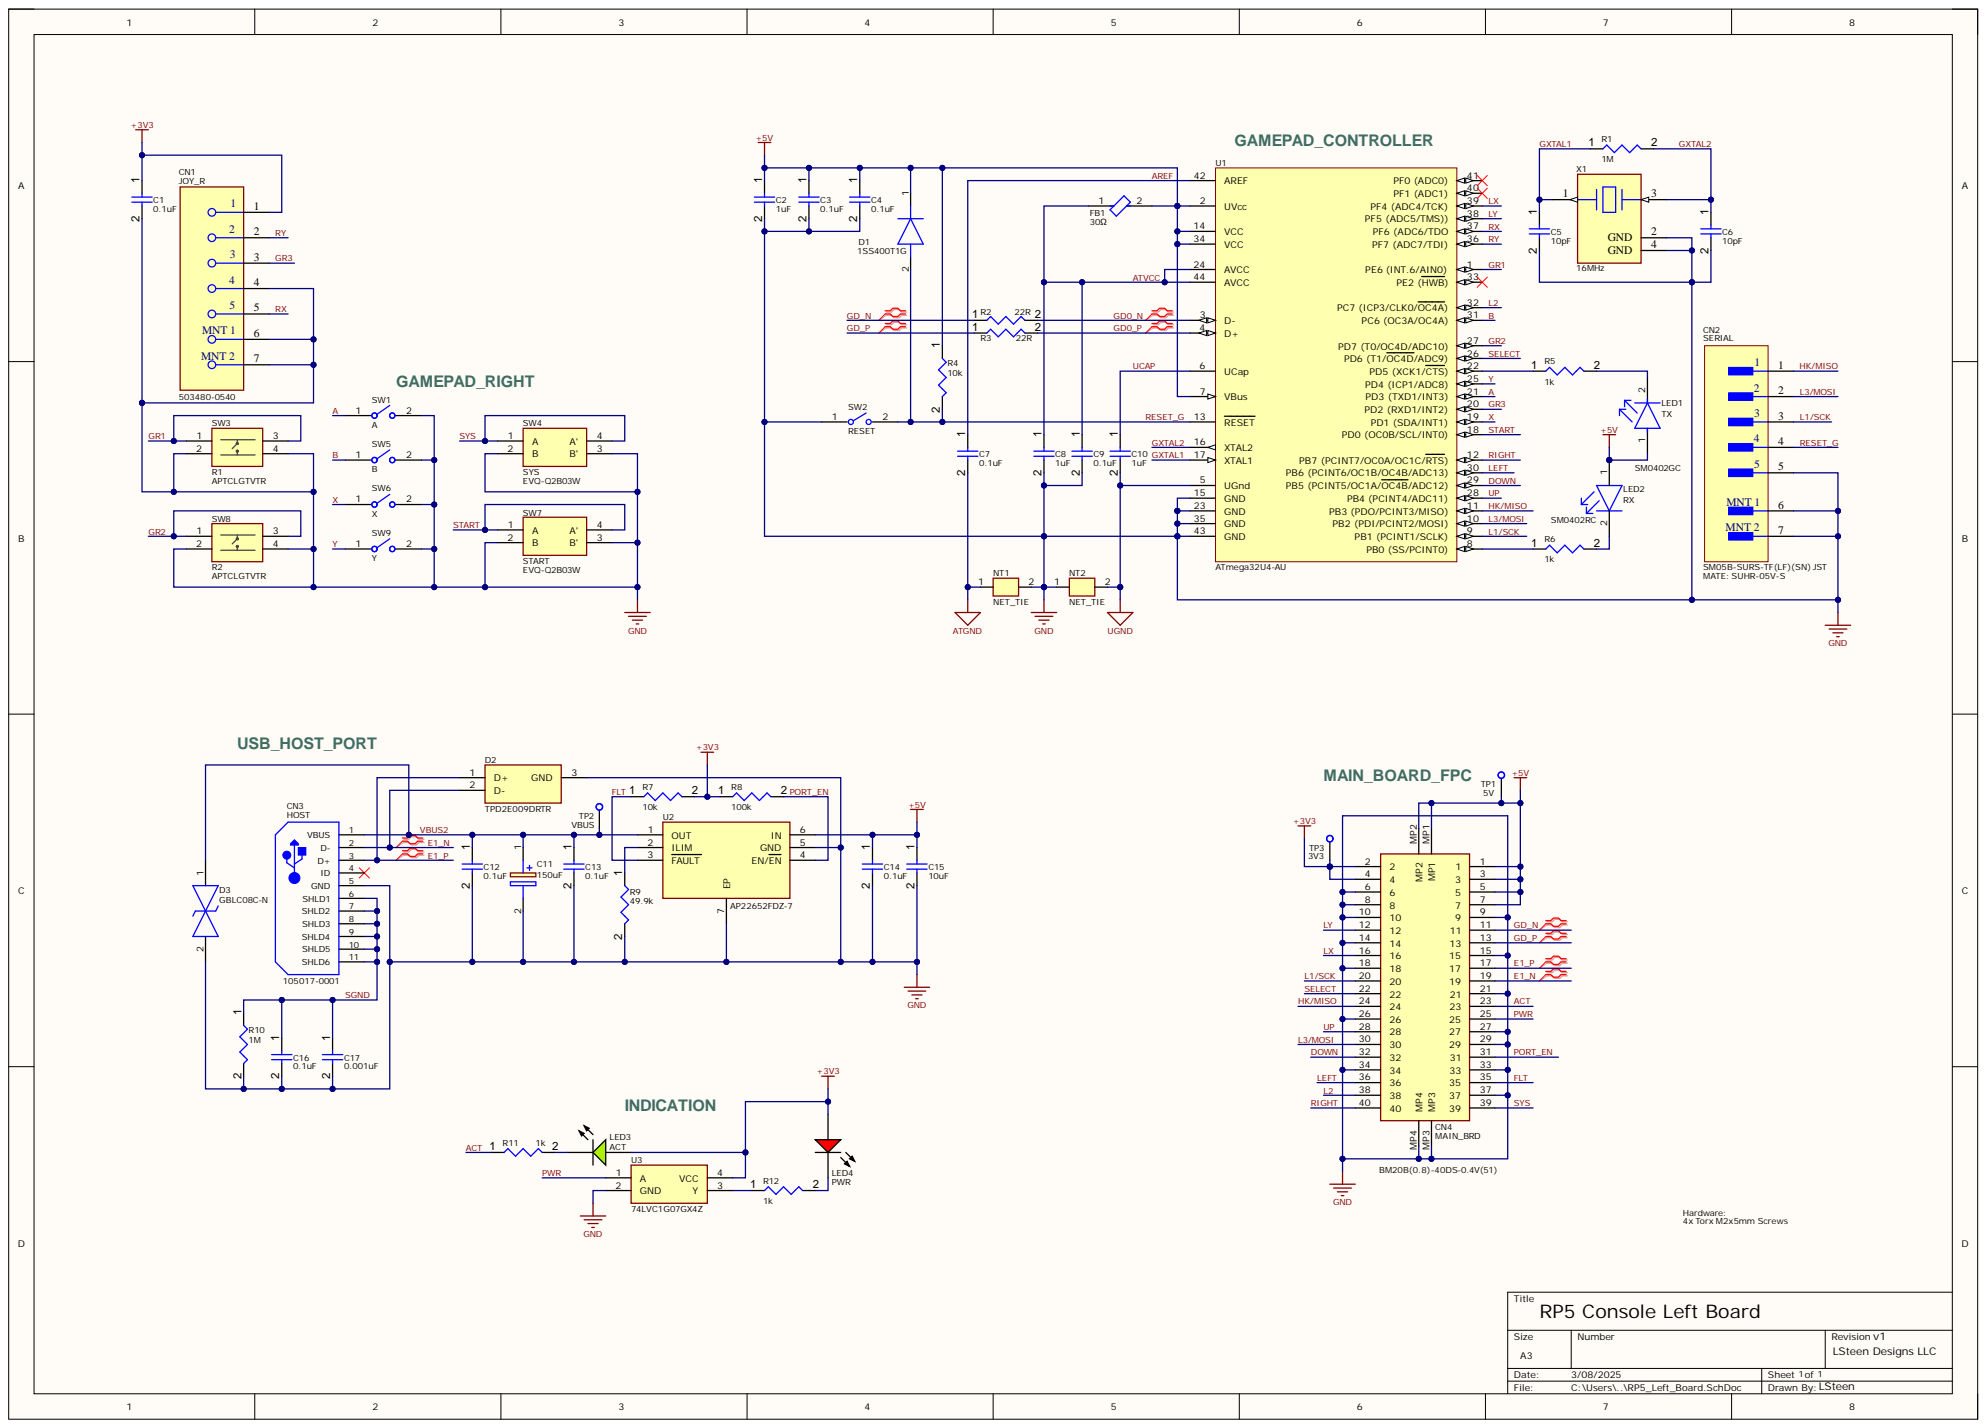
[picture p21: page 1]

SM05B-SURS-TF(LF)(SN) JST
MATE: SUHR-05V-S

FLT | PORT_EN

VBUS2

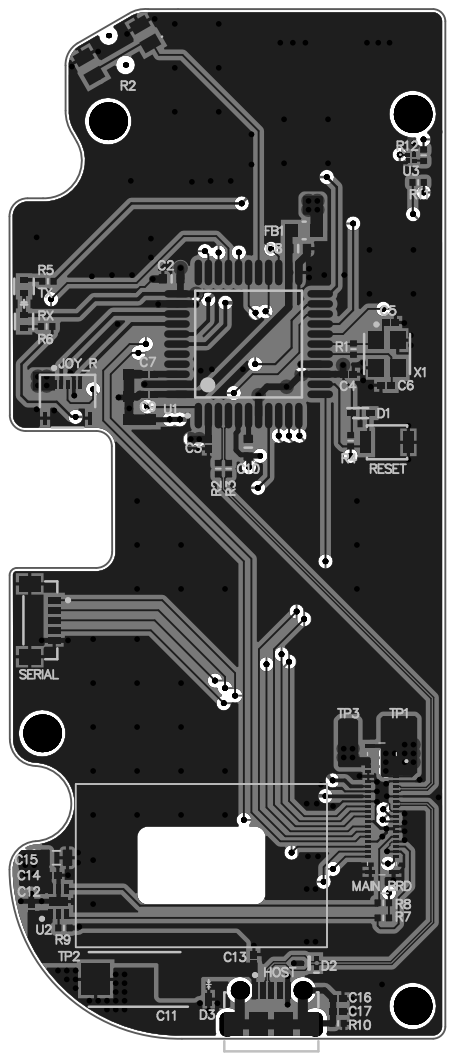
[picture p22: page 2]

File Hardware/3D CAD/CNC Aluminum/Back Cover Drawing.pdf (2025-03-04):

2
1

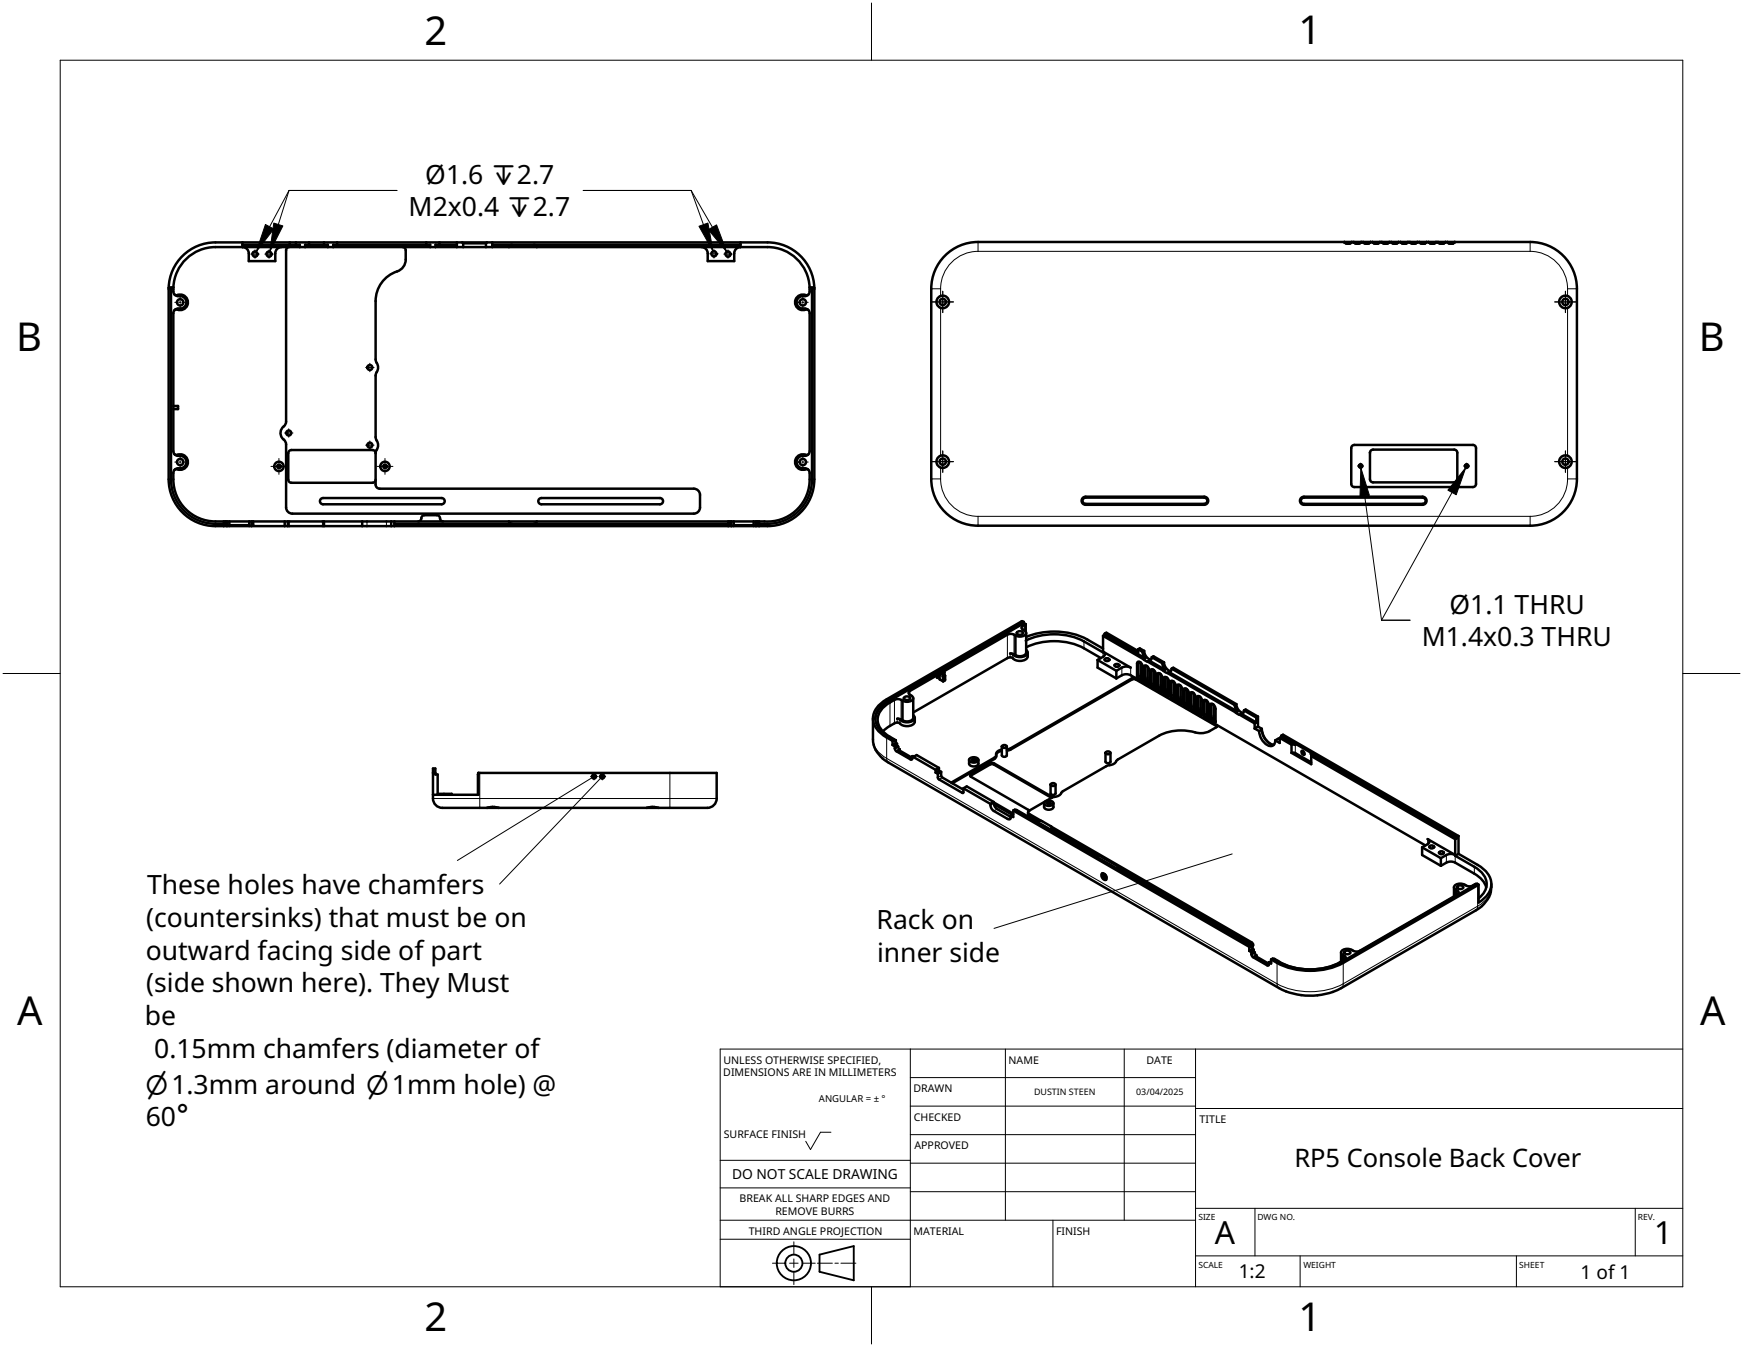
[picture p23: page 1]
MATERIAL; FINISH; Rack on inner side; Ø1.1 THRU M1.4x0.3 THRU

These holes have chamfers
(countersinks) that must be on
outward facing side of part
(side shown here). They Must
0.15mm chamfers (diameter of
1.3mm around 1mm hole) @

UNLESS OTHERWISE SPECIFIED, DIMENSIONS ARE IN MILLIMETERS ANGULAR = ± ° SURFACE FINISH | | NAME | DATE

DRAWN | DUSTIN STEEN | 03/04/2025

CHECKED | | | TITLE RP5 Console Back Cover

APPROVED

DO NOT SCALE DRAWING

BREAK ALL SHARP EDGES AND

REMOVE BURRS
THIRD ANGLE PROJECTION

SIZE A | DWG NO. | REV. 1

SCALE 1:2 | WEIGHT | SHEET 1 of 1

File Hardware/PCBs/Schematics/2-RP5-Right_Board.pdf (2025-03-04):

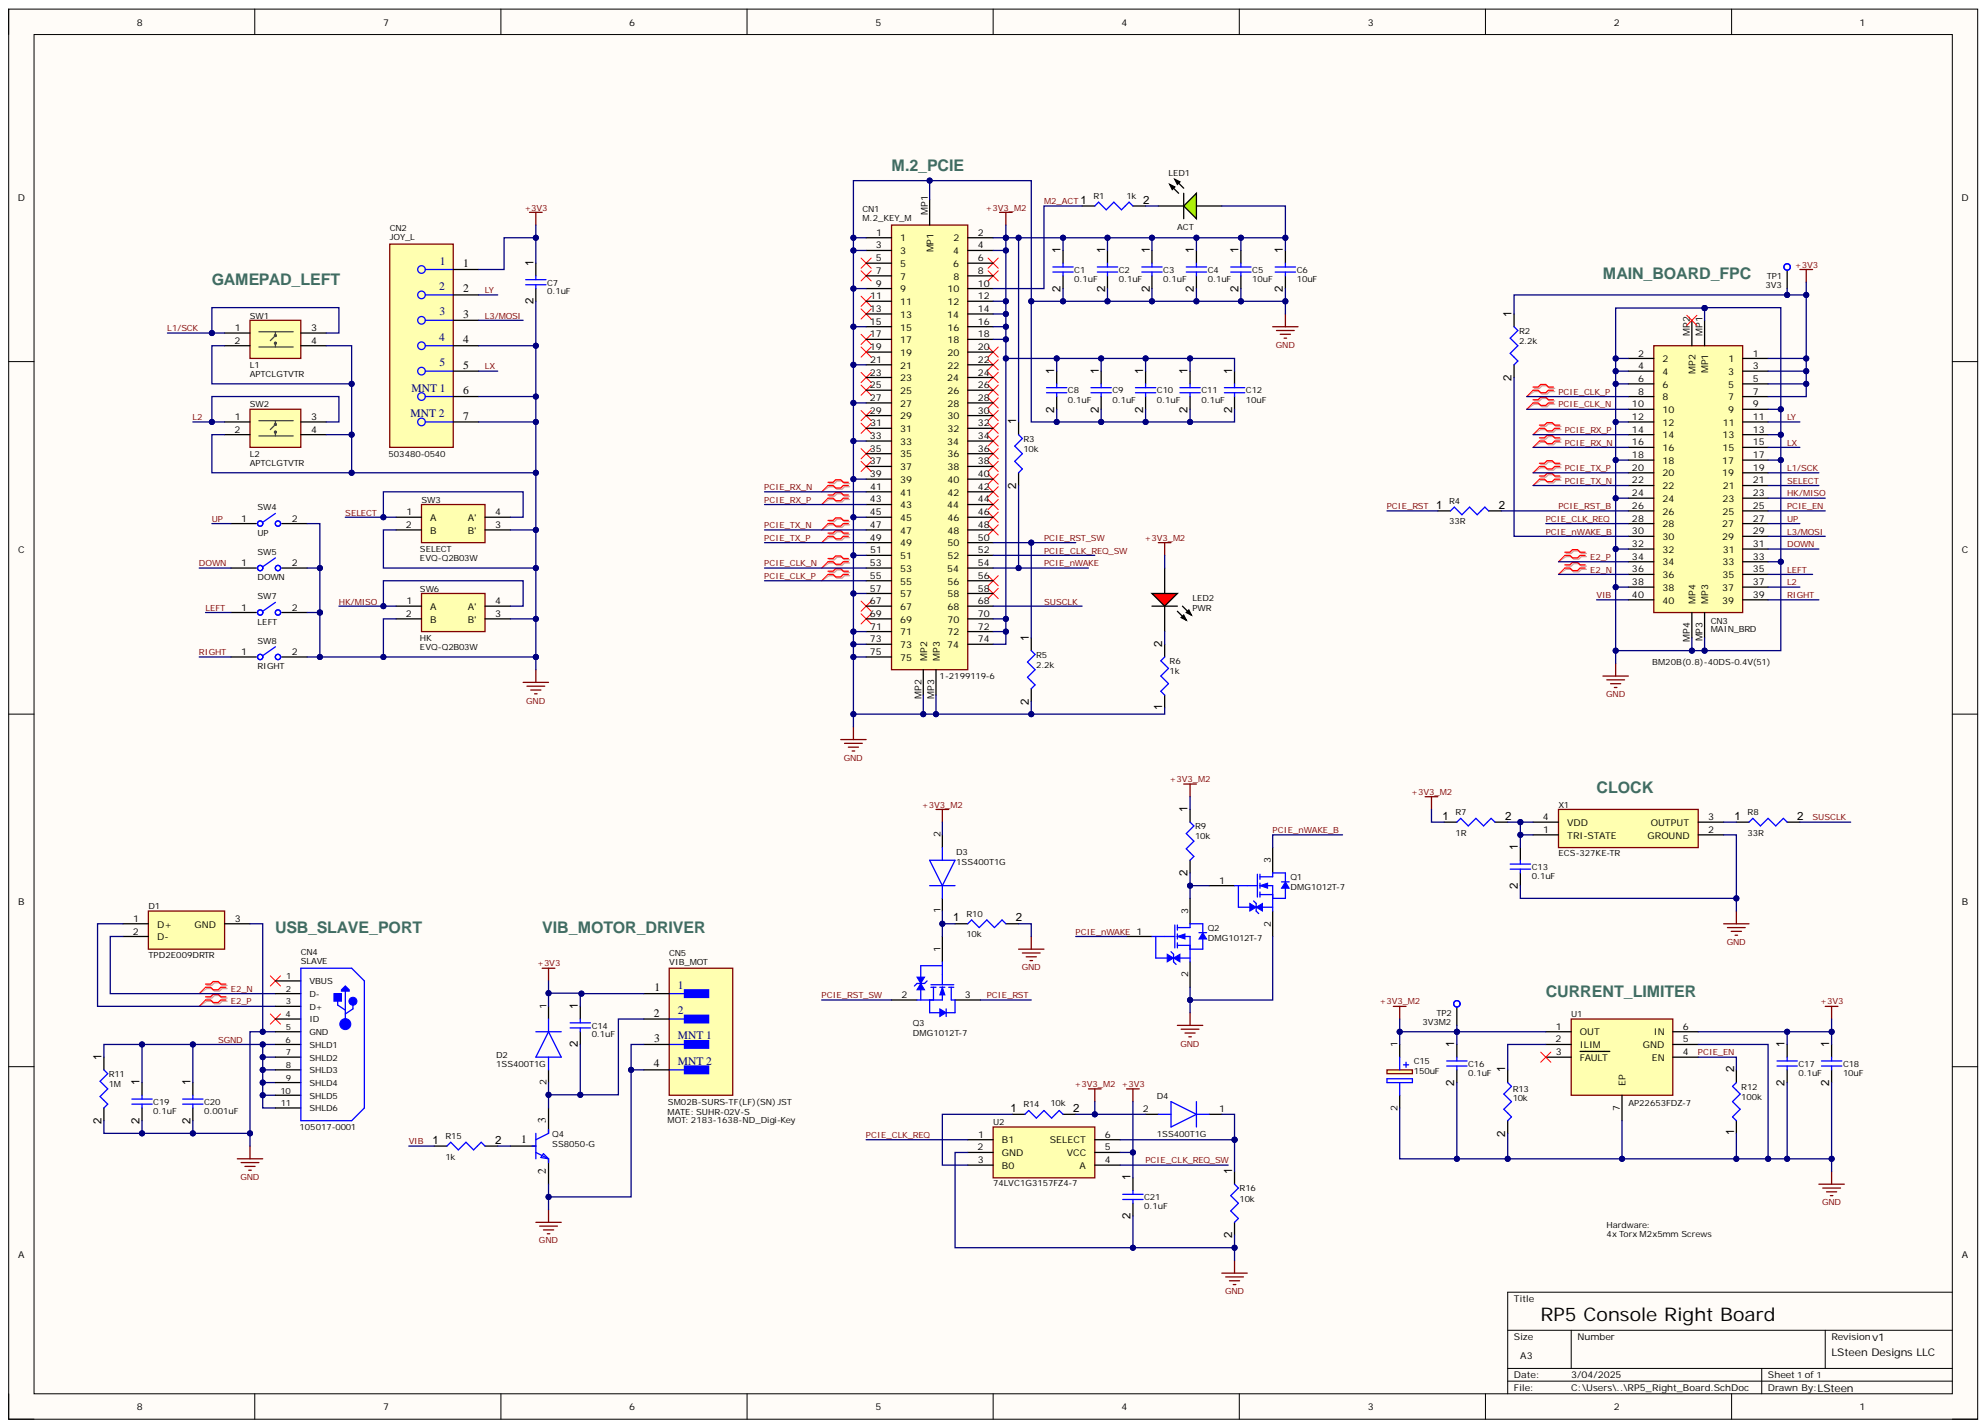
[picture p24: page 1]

SHLD3 8
SHLD4 9
SHLD5 10

SM02B-SURS-TF(LF)(SN) JST
MATE: SUHR-02V-S
MOT: 2183-1638-ND_Digi-Key

PCIE_CLK_REQ_SW

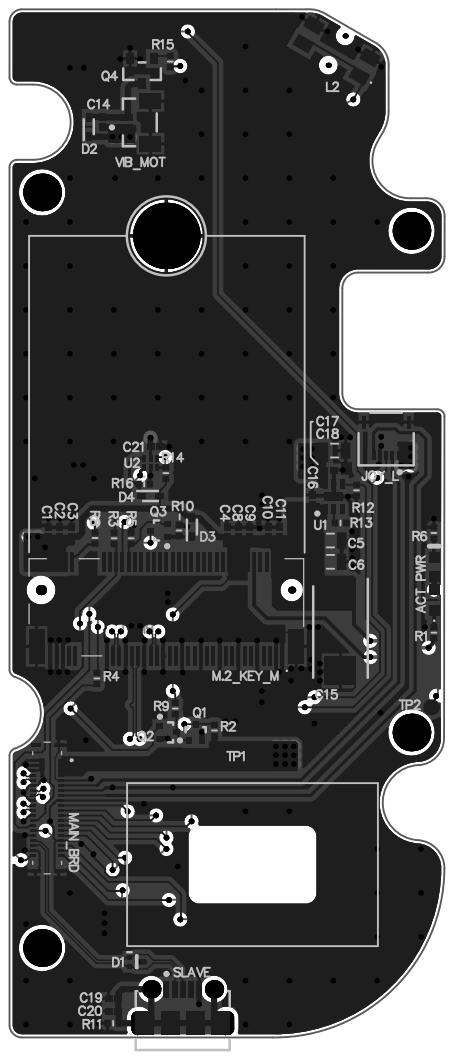
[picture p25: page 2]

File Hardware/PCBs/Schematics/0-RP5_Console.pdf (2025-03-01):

## RP5 Console System v1

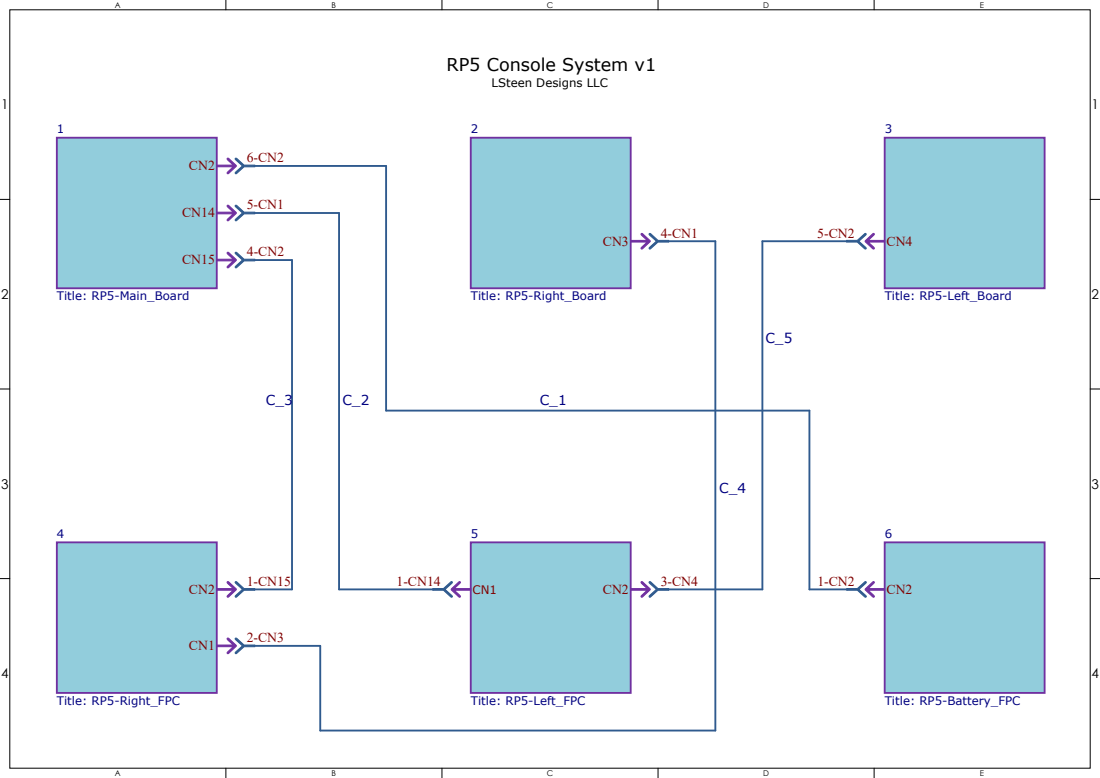
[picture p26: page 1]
Title: RP5-Main_Board; Title: RP5-Right_Board; Title: RP5-Left_Board; Title: RP5-Right_FPC; Title: RP5-Left_FPC; Title: RP5-Battery_FPC

LSteen Designs LLC

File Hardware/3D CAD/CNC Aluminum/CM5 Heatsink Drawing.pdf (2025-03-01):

2
1

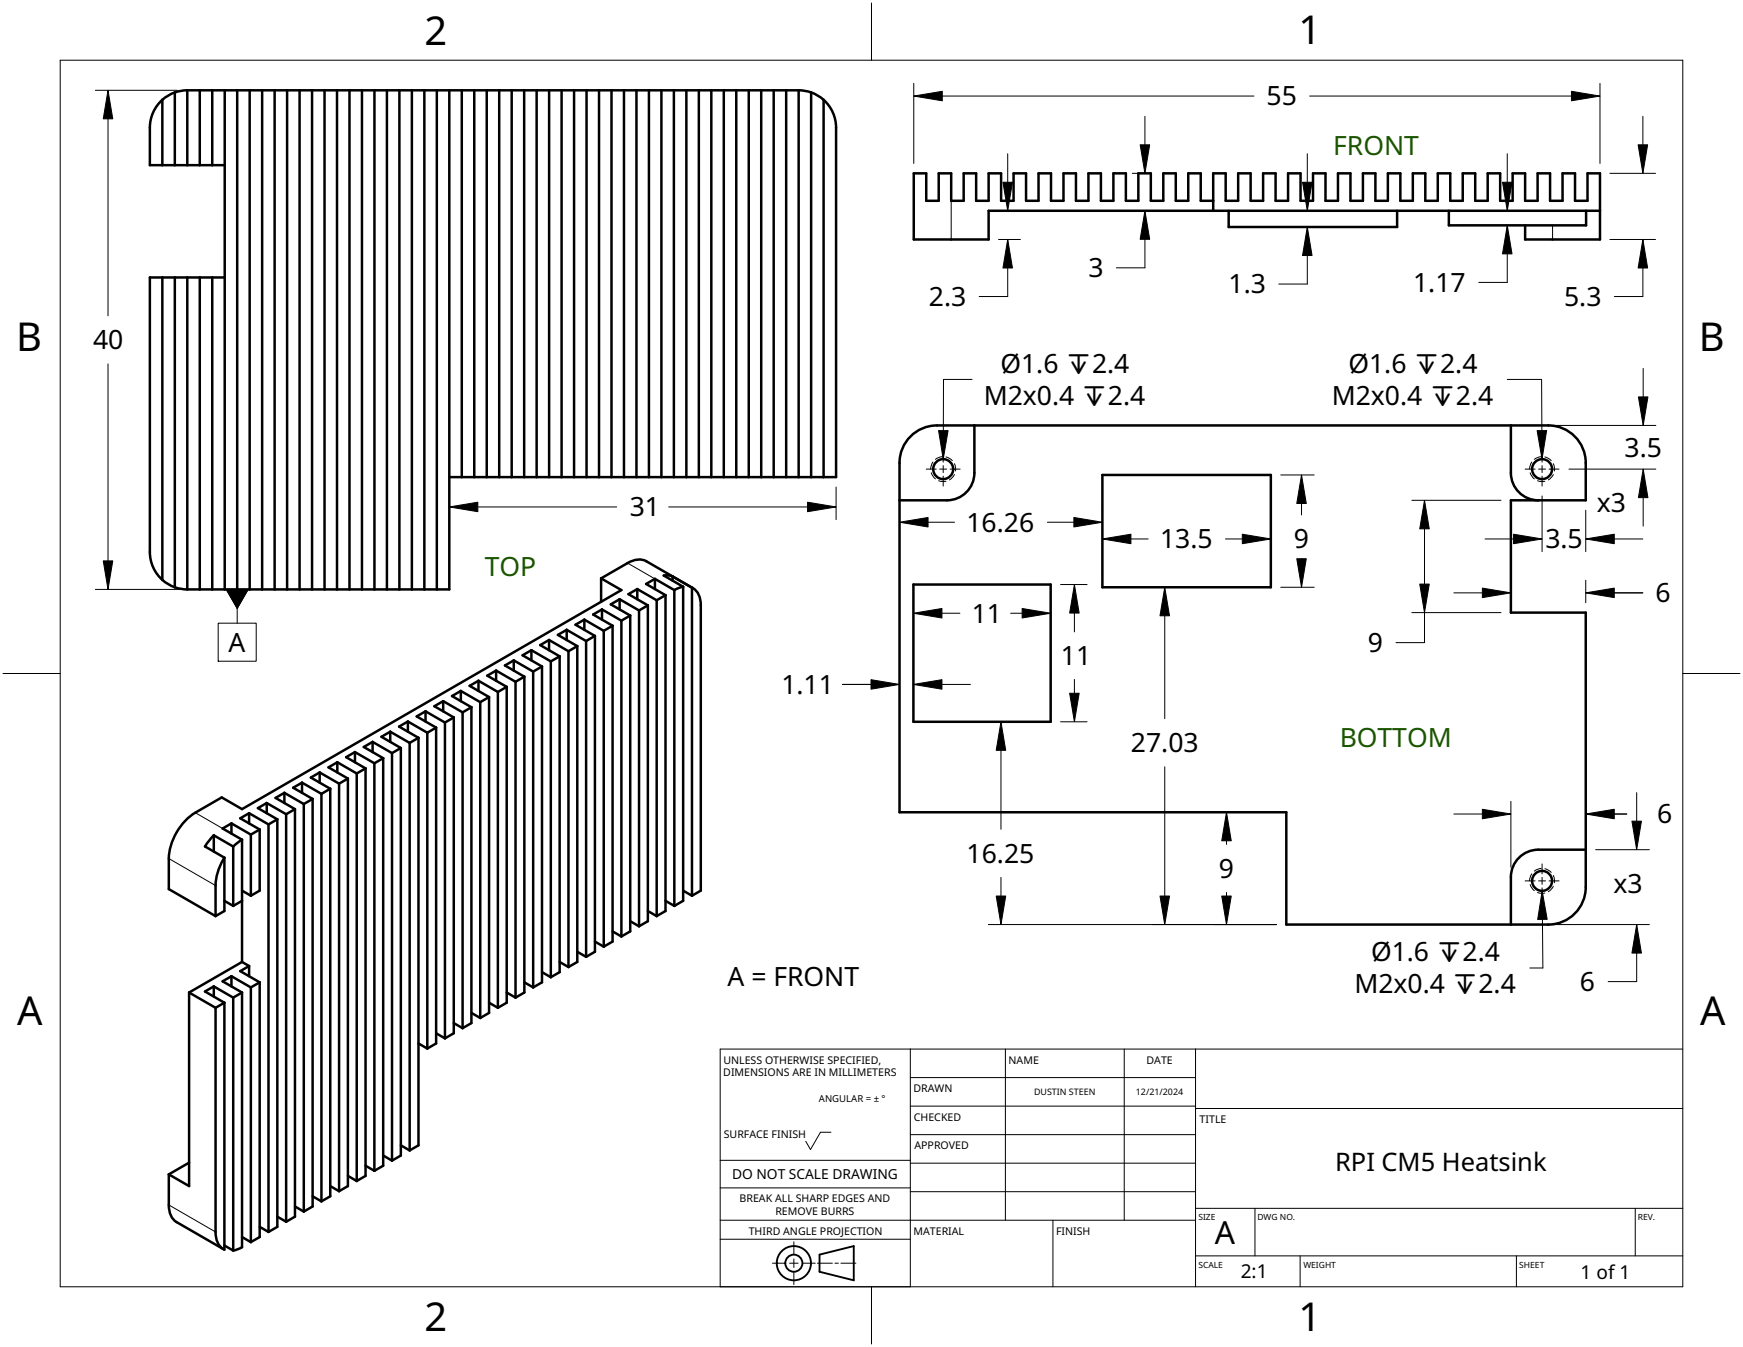
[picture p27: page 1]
MATERIAL; FINISH; TOP; BOTTOM; FRONT; A = FRONT

UNLESS OTHERWISE SPECIFIED, DIMENSIONS ARE IN MILLIMETERS ANGULAR = ± ° SURFACE FINISH | | NAME | DATE

DRAWN | DUSTIN STEEN | 12/21/2024

CHECKED | | | TITLE RPI CM5 Heatsink

APPROVED

DO NOT SCALE DRAWING

BREAK ALL SHARP EDGES AND

REMOVE BURRS
THIRD ANGLE PROJECTION

SIZE A | DWG NO. | REV.

SCALE 2:1 | WEIGHT | SHEET 1 of 1

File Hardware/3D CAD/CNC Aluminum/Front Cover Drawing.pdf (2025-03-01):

2
1

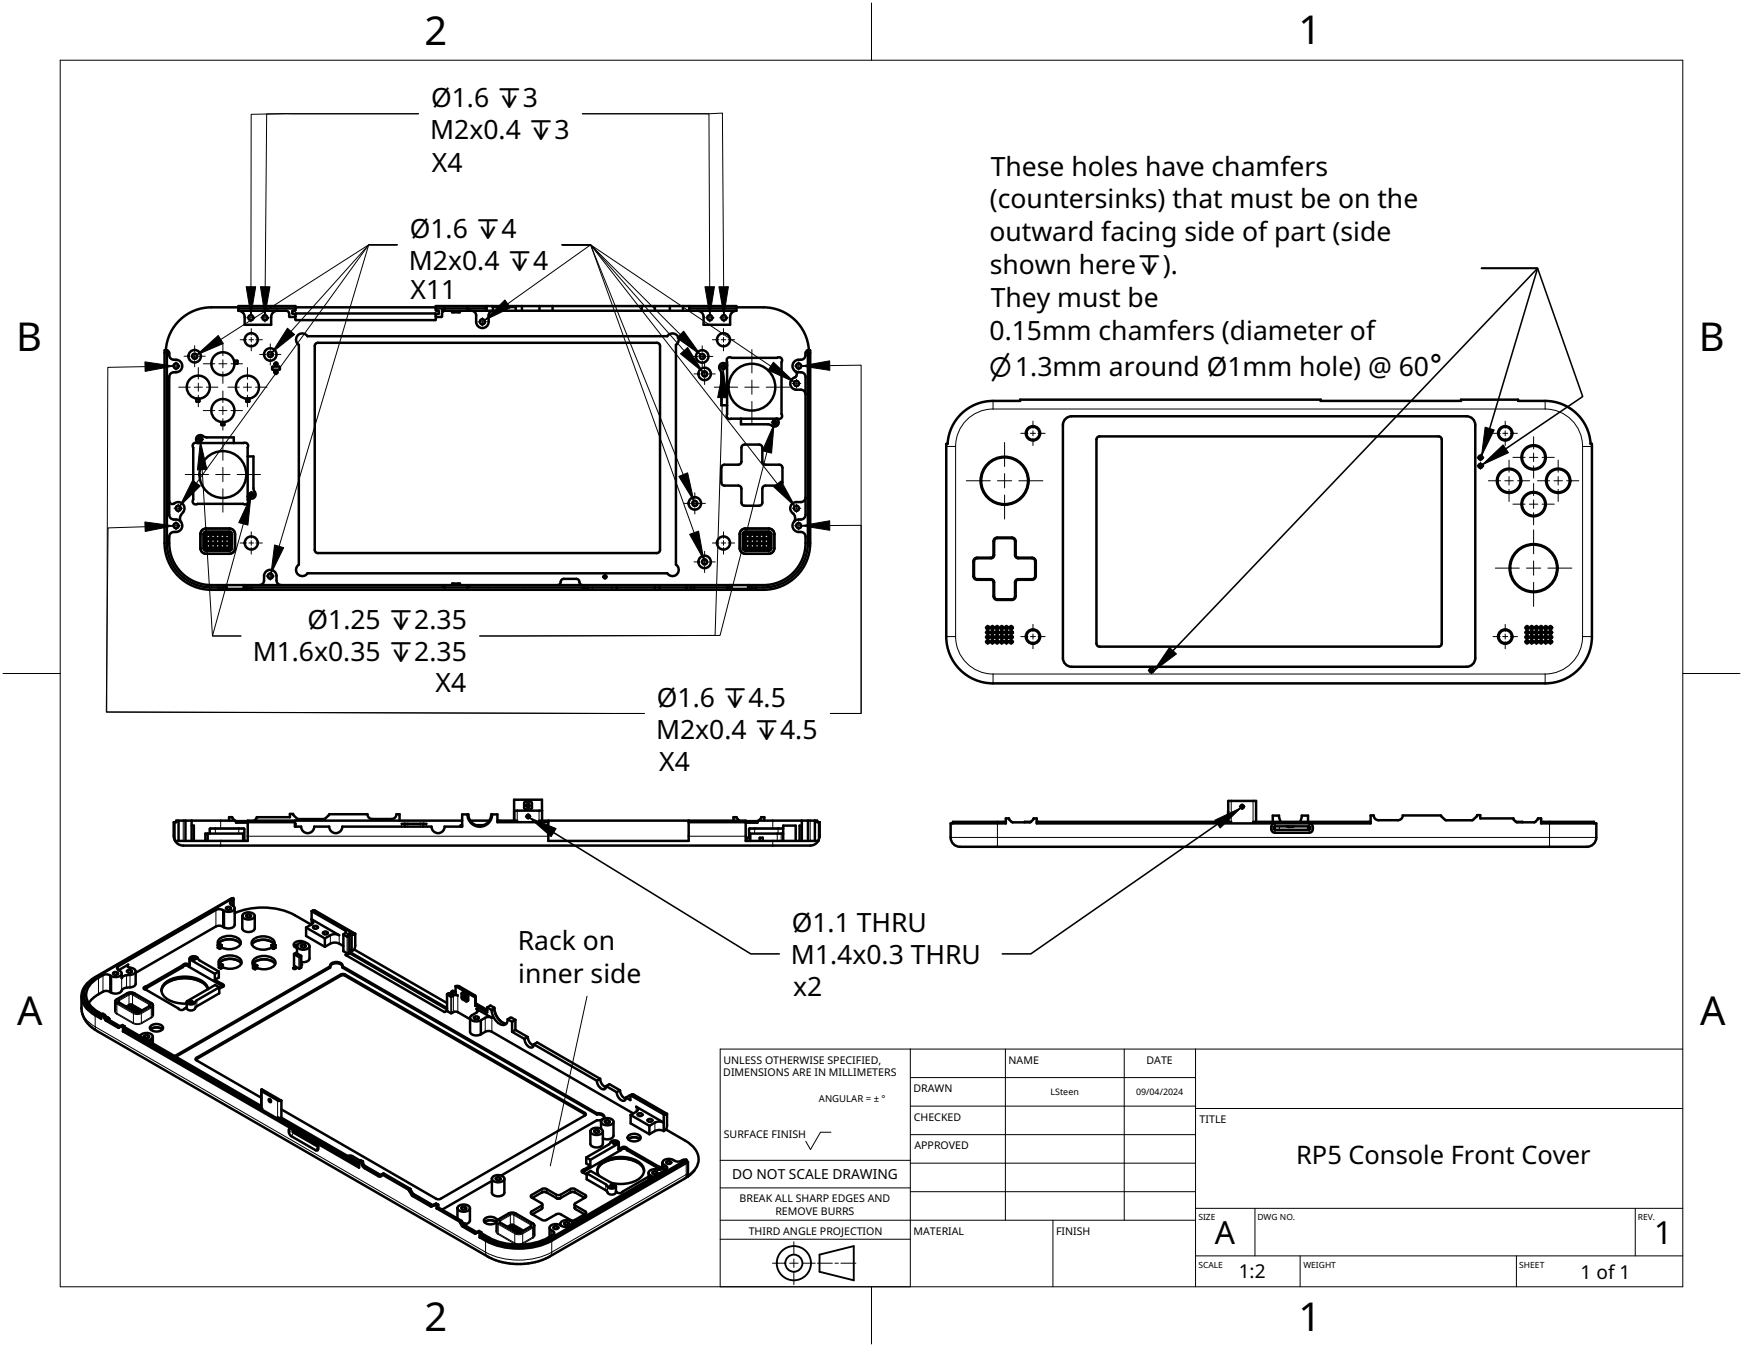
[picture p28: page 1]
MATERIAL; FINISH; Ø1.1 THRU M1.4x0.3 THRU x2; Rack on inner side

These holes have chamfers
(countersinks) that must be on the
outward facing side of part (side
shown here).
They must be
0.15mm chamfers (diameter of
1.3mm around Ø1mm hole) @ 60°

UNLESS OTHERWISE SPECIFIED, DIMENSIONS ARE IN MILLIMETERS ANGULAR = ± ° SURFACE FINISH | | NAME | DATE

DRAWN | LSteen | 09/04/2024

CHECKED | | | TITLE RP5 Console Front Cover

APPROVED

DO NOT SCALE DRAWING

BREAK ALL SHARP EDGES AND

REMOVE BURRS
THIRD ANGLE PROJECTION

SIZE A | DWG NO. | REV. 1

SCALE 1:2 | WEIGHT | SHEET 1 of 1

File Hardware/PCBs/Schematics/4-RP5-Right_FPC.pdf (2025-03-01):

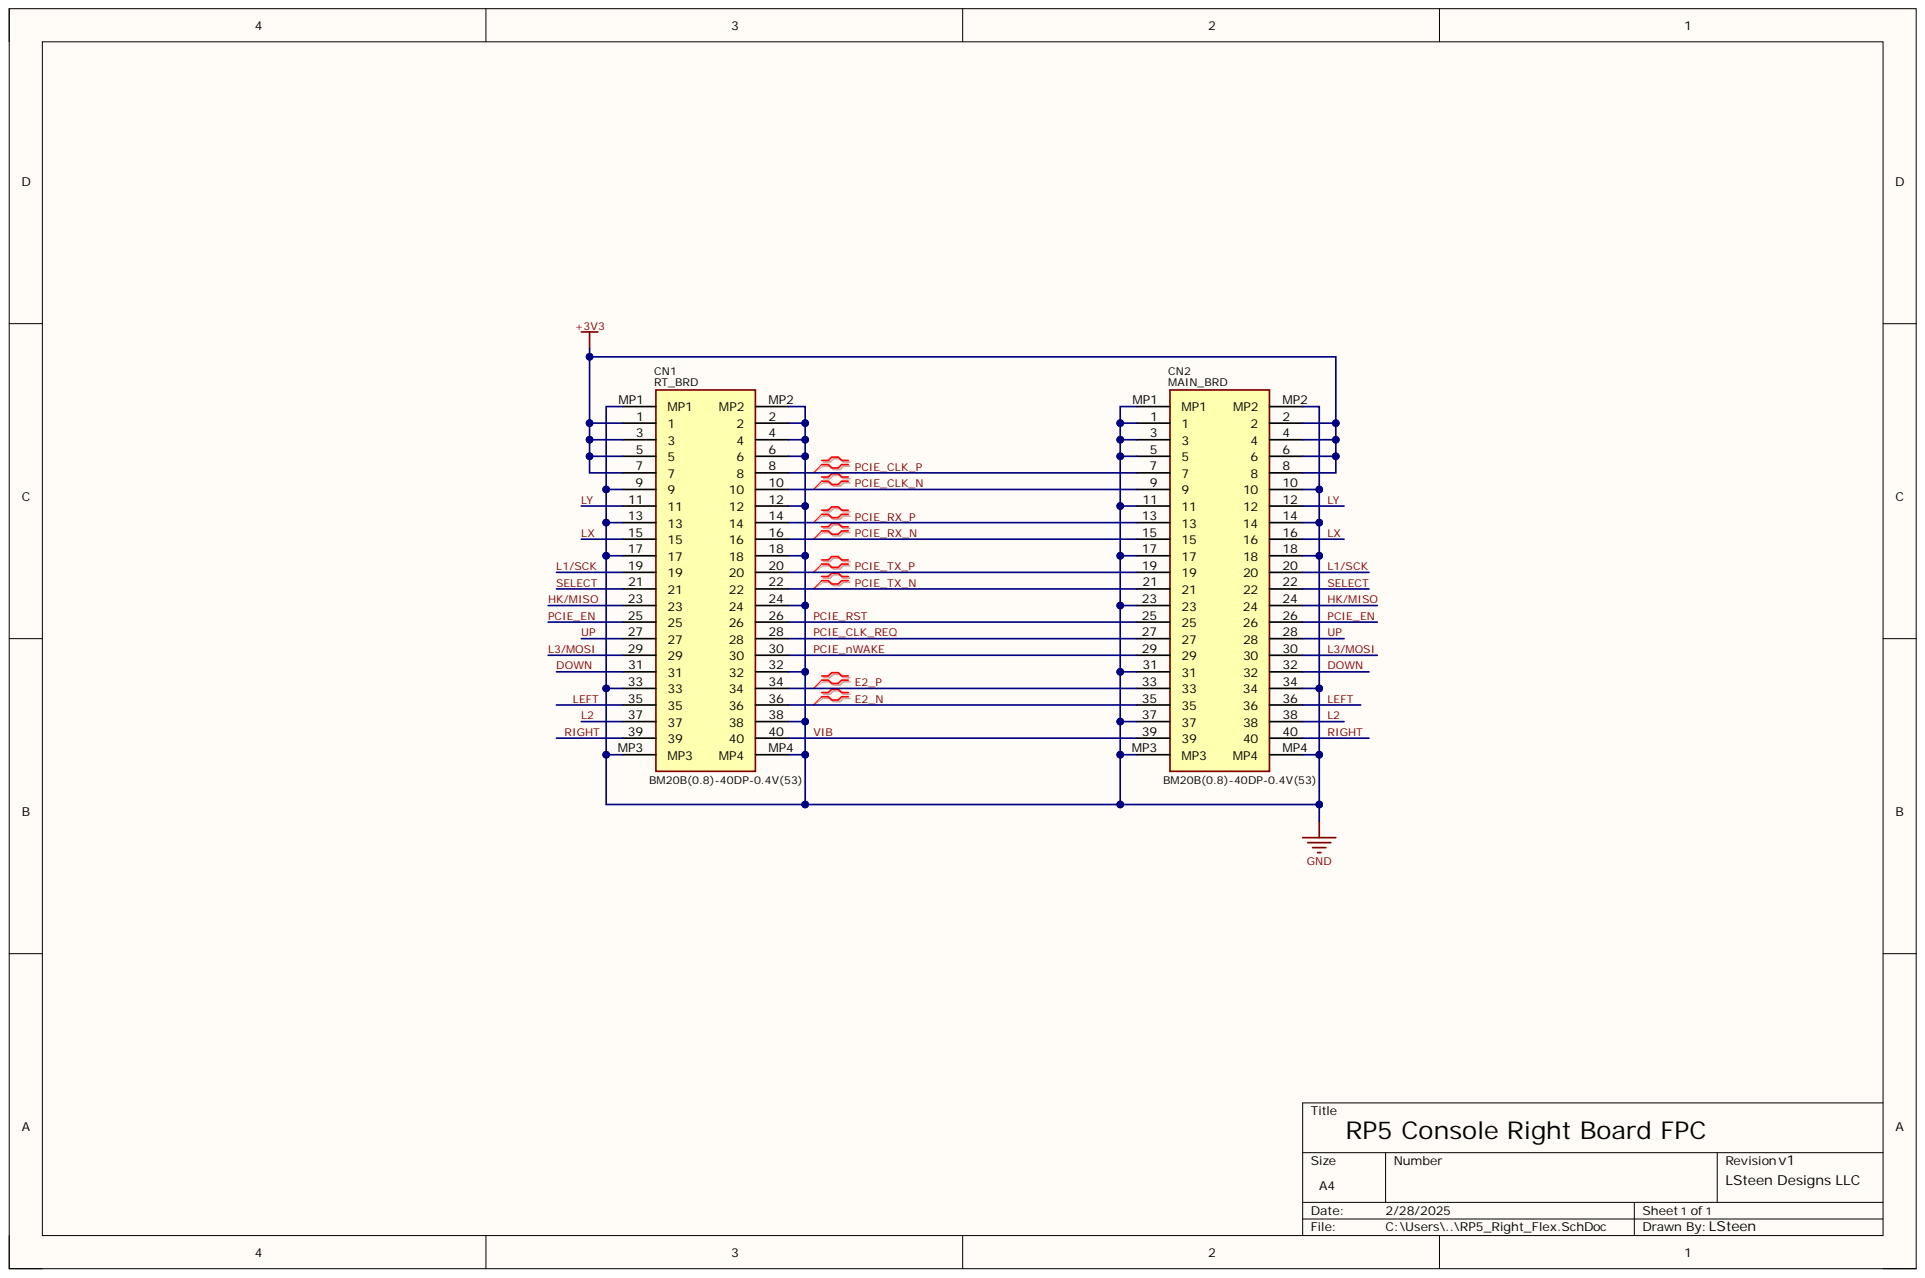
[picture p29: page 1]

9 | 1 0 | PCI E _CLK_ N | 9 | 1 0 | L Y L X L SE L L E L 2
1 1 1 3 | | 1 2 | PCI E _RX_ P | 1 1 | 1 2 1 4

1 5 1 7 | 1 6 | PCI E _RX_ N | 1 5 | 1 6 1 8

1 8 | PCI E _TX_ P | 1 7

2 2 | PCI E _TX_ N | 2 1
2 4 | PCI E _RST | 2 3

2 8 | PCI E _CLK_RE Q | 2 7
3 0 | PCI E _ n WAKE | 2 9
3 2 | E 2 _ P | 3 1

Si z e A 4 | Numbe r | Revisi o n v 1 LSteen Designs LLC

Date: 2/28/2 0 2 5 | Sheet o f 1
Fi l e : C:\Users\..\RP5_Right_Flex.Sch D o c | Drawn By: LSt e e n

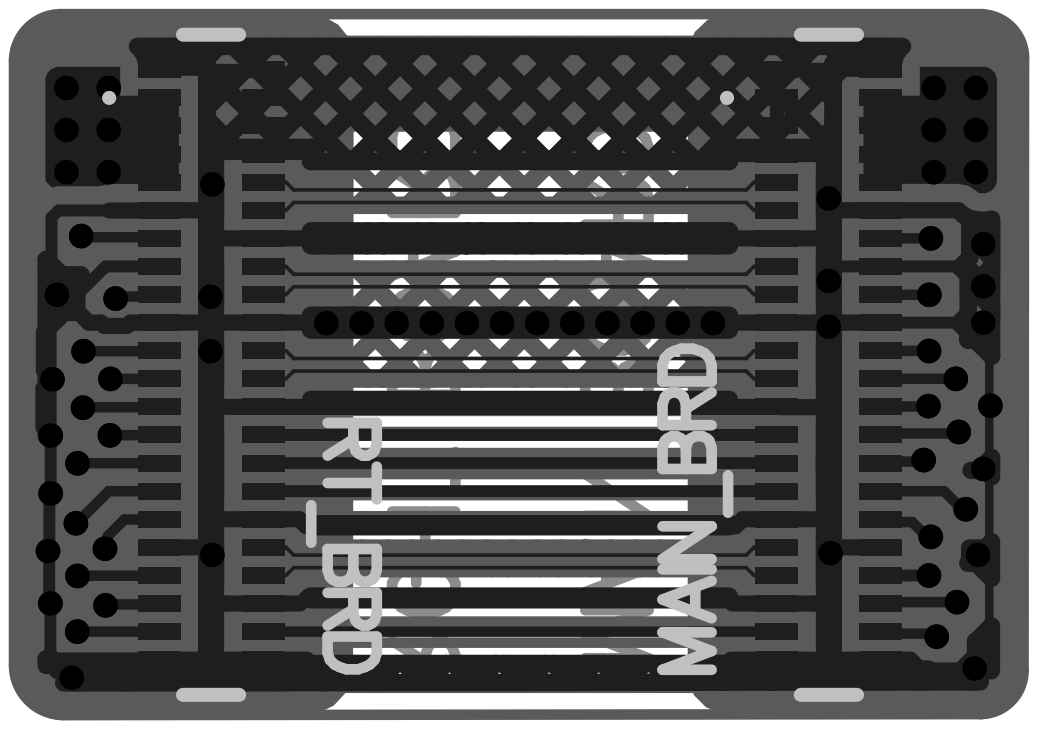
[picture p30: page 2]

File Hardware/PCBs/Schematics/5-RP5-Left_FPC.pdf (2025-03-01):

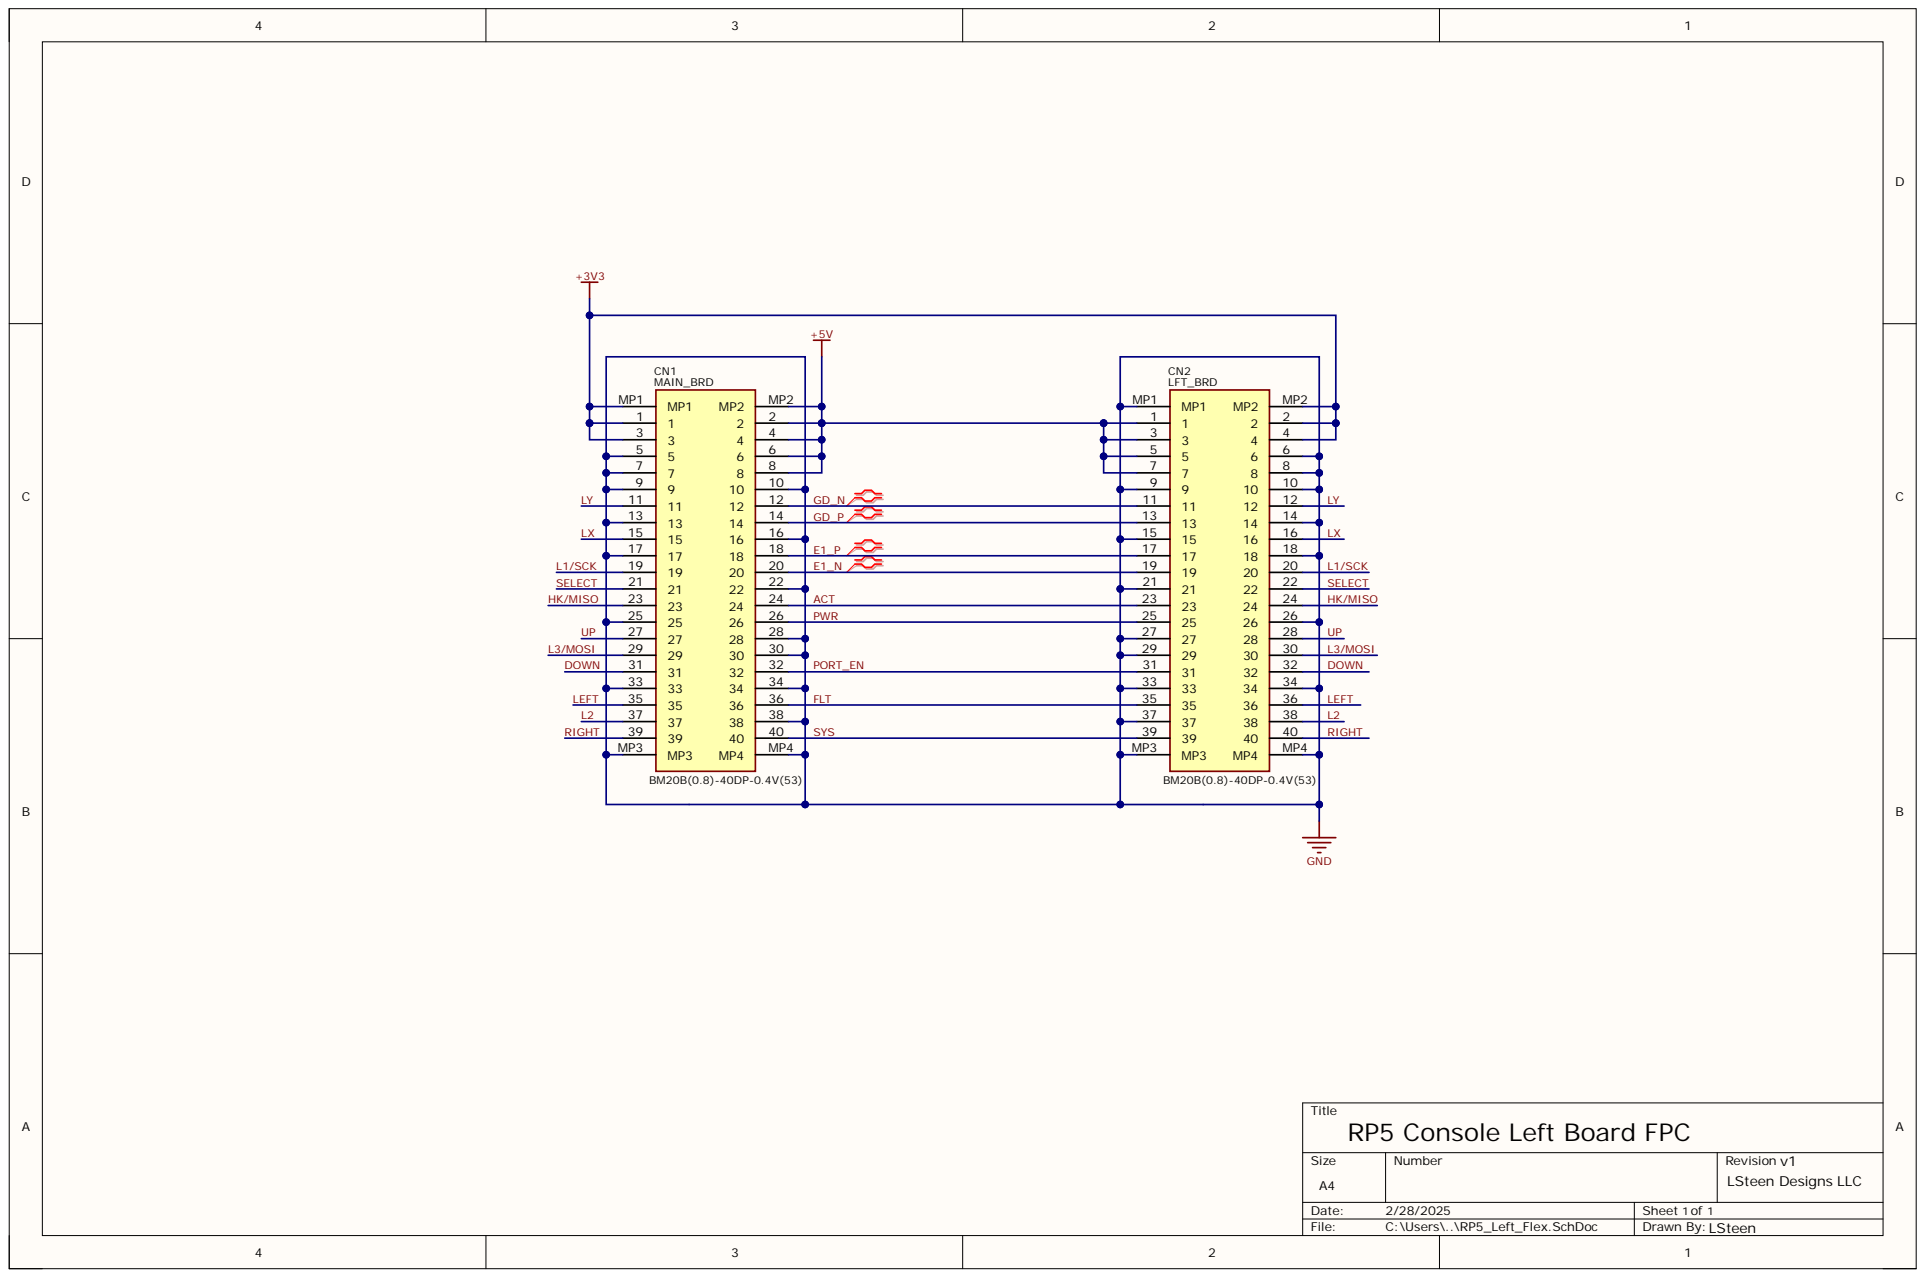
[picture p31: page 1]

3 | 3 4 5 6 7 8 9 1 0 1 1 1 2 1 3 1 4 1 5 1 6 1 7 1 8 1 9 2 0 2 1 2 2 2 3 2 4 2 5 2 6 2 7 2 8 2 9 3 0 3 1 3 2 3 3 3 4 3 5 3 6 3 7 3 8 3 9 4 0 | 4 | _ N | 3 | 3 4 5 6 7 8 9 1 0 1 1 1 2 1 3 1 4 1 5 1 6 1 7 1 8 1 9 2 0 2 1 2 2 2 3 2 4 2 5 2 6 2 7 2 8 2 9 3 0 3 1 3 2 3 3 3 4 3 5 3 6 3 7 3 8 3 9 4 0 | 4
5 | | | 6 | | 5 | | 6 | L Y L X L SE L L E L 2

2 6 | SYS E1_ PW R | 2 5
2 2 | ACT | 2 1

2 7 2 9 3 1 3 3 | | 2 8 | PORT_ E N | 2 7 | 2 8 3 0 3 2 3 4

RP5 Console Left Board FPC1 Si z e A 4 | Numbe r | Revisi o n v 1 LSteen Designs LLC

Date: 2/28/2 0 2 5 | Sheet o f 1
Fi l e : C:\Users\..\RP5_Left_Flex.SchD o c | Drawn By: LSt e e n

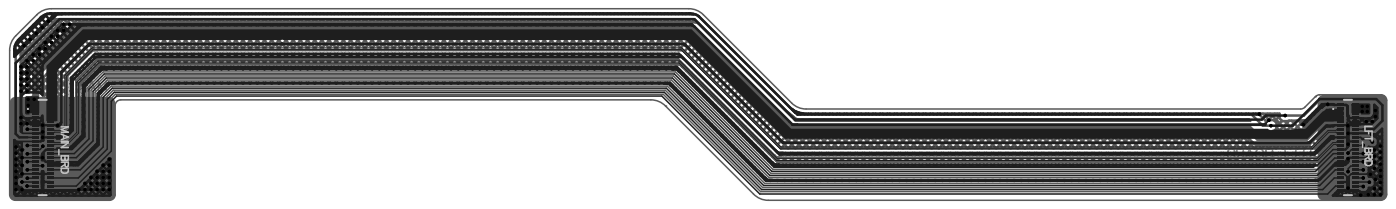
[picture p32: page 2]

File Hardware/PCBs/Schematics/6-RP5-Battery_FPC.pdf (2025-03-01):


Si z e A 4 | Numbe r | Revisi o n v 1 LSteen Designs LLC

Date: 2/28/2 0 2 5 | Sheet 1 o f 1
Fi l e : C:\Users\..\RP5_Bat tery_Flex.Sch D o c | Drawn By: LSt e e n


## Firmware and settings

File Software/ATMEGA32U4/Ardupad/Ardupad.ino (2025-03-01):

/*  
 * Ardupad for Atmega32u4
 * Default configuration - 2 Joysticks, 13 Buttons, 1 Dpad.
 * 
 * Joystick calibration:
 * 1: Press the buttons on pins D0 and D3 simultaneously to put the controller into calibration mode.
 * 2: Centre both joysticks and press the button on pin D1 to record mid position, RX LED will blink once to confirm step complete.
 * 3: Move both joysticks to full extents of travel several times to record maximum axis values.
 * 4: Press button on D1 again. RX LED will blink once more to confirm.
 * 5: Calibration is now complete and stored.
 * 
 * If you're using this controller with Windows, you will also need to run the windows joypad calibration once you've completed the internal calibration.
 * If you change joysticks or your centerpoint drifts (thanks, nintendo) re-running the internal calibration should solve the problem.
 * 
 * Note: Whilst controller is in calibration mode all USB control output will cease until calibration is complete or controller is restarted.
 * 
 * Created by - Daniel McKenzie
 * 10-03-2021 v1.3
 */

#include <Joystick.h> //https://github.com/MHeironimus/ArduinoJoystickLibrary
#include <EEPROM.h>

//Options
const bool cycleTimeTest = false; //Enable to test CPU Cycle time.
#define baudrate 115200 //Baudrate for serial. Used only for polling rate test

//Define button pins
byte buttonCount = 13; //Number of buttons in use. Change length of buttonPins, lastButtonState and currentButtonState to match.
byte buttonPins[13] = {0,1,2,3,4,5,6,7,12,13,14,15,16}; //Array to store digital pins used for buttons. Length must be the same as buttonCount.
byte dpadPins[4] = {8,11,9,10}; //Up, Right, Down, Left. Do not change order of directions.

//Button state arrays
byte dpadPinsState[4];  //Empty State array for dPad
byte lastButtonState[13]; //Empty State array for buttons last sent state. Must be same length as buttonPins
byte currentButtonState[13]; //Empty State array for buttons. MMust be same length as buttonPins

//Define Analog Pins for joysticks
const int leftJoyX = A3;
const int leftJoyY = A2;
const int rightJoyX = A1;
const int rightJoyY = A0;

//Joystick Settings
const bool invertLeftY = false;   //------------------------------------------
const bool invertLeftX = false;    //Change these settings for Inverted mounting 
const bool invertRightY = true;  //of joysticks.
const bool invertRightX = true;  //------------------------------------------
const int deadBandLeft = 10;     //
const int deadBandRight = 10;    //Joystick deadband settings. Deadband is the same for both axis on each joystick.
const bool useDeadband = true;    //
const int earlyLeftX = 30;   //--------------------------------------------------
const int earlyLeftY = 30;   //Distance from end of travel to achieve full axis movement. 
const int earlyRightY = 30;  //This helps square out each axis response to allow full movement speed with direction input.
const int earlyRightX = 30;  //--------------------------------------------------
boolean scaledJoystickOutput = true; //Enable joystick scaling. Needed for switch joysticks due to uneven axis travels. Disabling will save some compute time if your joystick works well without it.

//Main Joystick setup
Joystick_ Joystick(JOYSTICK_DEFAULT_REPORT_ID,JOYSTICK_TYPE_GAMEPAD,
buttonCount, 0,       // Button Count, Hat Switch Count
true, true, true,     // X Y Z
true, true, true,  // Rx, Ry, Rz
false, false,          // Rudder, Throttle
false, false, false); // Accelerator, Brake, Steering

//Default Joystick calibration settings and EEPROM storage Address
int minLeftX = 330; //EEPROM Adr = 1
int maxLeftX = 830; //EEPROM Adr = 3
int midLeftX = 512; //EEPROM Adr = 5

int minLeftY = 205; //EEPROM Adr = 7
int maxLeftY = 635; //EEPROM Adr = 9
int midLeftY = 477; //EEPROM Adr = 11

int minRightY = 215; //EEPROM Adr = 13
int maxRightY = 730; //EEPROM Adr = 15
int midRightY = 529; //EEPROM Adr = 17

int minRightX = 300; //EEPROM Adr = 19
int maxRightX = 780; //EEPROM Adr = 21
int midRightX = 525; //EEPROM Adr = 23

//Joystick LookUp Tables, compiled at startup or after joystick calibration.
byte leftXLUT[350];
byte leftYLUT[350];
byte rightXLUT[350];
byte rightYLUT[350];

//All variables below general use, not used for configuration.
boolean calibrationMode = false;
int calibrationStep = 1;
long pollingTest;
float lastPollingMS;
long lastPollingReport;

void setup() { 
  //Needed for Retropie to detect axis.
  Joystick.setXAxisRange(0, 254);
  Joystick.setYAxisRange(0, 254);
  Joystick.setZAxisRange(0, 254);
  Joystick.setRxAxisRange(0, 254);
  Joystick.setRyAxisRange(0, 2);
  Joystick.setRzAxisRange(0, 2);
  
  if(cycleTimeTest){
    Serial.begin(baudrate);
    while (!Serial); //Needed on 32u4 based arduinos for predictable serial output.
  }
  Joystick.begin(false); //Initialise joystick mode with auto sendState disabled as it has a huge processor time penalty for seemingly no benefit.
  
  for(int i = 0; i < buttonCount; i++){ //Set all button pins as input pullup. Change to INPUT if using external resistors.
    pinMode(buttonPins[i], INPUT_PULLUP);
  }
  for(int i = 0; i < 4; i++){ //Set all dpad button pins as input pullup.
    pinMode(dpadPins[i], INPUT_PULLUP);
  }
  
  eepromLoad(); //Check for stored joystick settings and load if applicable.
  rebuildLUTs(); //Build joystick LUT's from stored calibration values.
}

void loop() {
  buttonRead();
  if(!calibrationMode){
    joypadButtons();
    joystickInput();
    dPadInput();
    Joystick.sendState(); //Update input changes
  } else {
    joystickCalibration();
  }
  if(lastButtonState[0] == HIGH && lastButtonState[3] == HIGH){ //If this combination of buttons is pressed, begin joystick calibration. (Start and right joystick button)
    Serial.println("Calibration Mode Triggered");
    calibrationMode = true;
  }
  if(cycleTimeTest){
    pollingRateTest();
  }
}

void rebuildLUTs(){
  joystickBuildLUT(leftXLUT, minLeftX, midLeftX, maxLeftX, earlyLeftX, deadBandLeft);
  joystickBuildLUT(leftYLUT, minLeftY, midLeftY, maxLeftY, earlyLeftY, deadBandLeft);
  joystickBuildLUT(rightXLUT, minRightX, midRightX, maxRightX, earlyRightX, deadBandRight);
  joystickBuildLUT(rightYLUT, minRightY, midRightY, maxRightY, earlyRightY, deadBandRight);
}

void pollingRateTest(){ //Reports current polling rate in MS every second.
  float pollingMS = (micros() - lastPollingMS) / 1000;
  lastPollingMS = micros();
  if(millis() > lastPollingReport + 1000){ //If more than 1 second has passed:
    Serial.print(pollingMS);
    Serial.println("ms");
    lastPollingReport = millis();
  }
}

void buttonRead(){ //Read button inputs and set state arrays.
  for (int i = 0; i < buttonCount; i++){
    int input = !digitalRead(buttonPins[i]);
    if (input != lastButtonState[i]){
      lastButtonState[i] = input;
    }
  }
  for(int i = 0; i < 4; i++){
    int input = !digitalRead(dpadPins[i]);
    if (input != dpadPinsState[i]){
      dpadPinsState[i] = input;
    }
  }
}

void joypadButtons(){ //Set joystick buttons for USB output
  for(int i = 0; i < buttonCount; i++){
    if(lastButtonState[i] != currentButtonState[i]){
      Joystick.setButton(i, lastButtonState[i]);
      Serial.print("Button: ");
      Serial.println(i);
      currentButtonState[i] = lastButtonState[i];
    }
  }
}

void dPadInput(){ //D-Pad as RY and RZ Axis
  if(dpadPinsState[0] == 1){ //Up
    Joystick.setRyAxis(2);
  } else if(dpadPinsState[2] == 1){ //Down
    Joystick.setRyAxis(0);
  } else {
    Joystick.setRyAxis(1);
  }
  if(dpadPinsState[1] == 1){ //Right
    Joystick.setRzAxis(2);
  } else if(dpadPinsState[3] == 1){ //Left
    Joystick.setRzAxis(0);
  } else {
    Joystick.setRzAxis(1);
  }
}

void eepromLoad(){ //Loads stored settings from EEPROM
  if(readIntFromEEPROM(1) != -1){ //Check Joystick Calibration in EEPROM is not Empty
    readJoystickConfig(); //Load joystick calibration from EEPROM
  }
}

void writeIntIntoEEPROM(int address, int number){ //Splits Int into BYTES for EEPROM
  byte byte1 = number >> 8;
  byte byte2 = number & 0xFF;
  EEPROM.write(address, byte1);
  EEPROM.write(address + 1, byte2);
}

int readIntFromEEPROM(int address){ //Converts BYTES to INT from EEPROM
  byte byte1 = EEPROM.read(address);
  byte byte2 = EEPROM.read(address + 1);
  return (byte1 << 8) + byte2;
}

void readJoystickConfig(){ //Read joystick calibration from EEPROM
//Left X
  minLeftX = readIntFromEEPROM(1);
  maxLeftX = readIntFromEEPROM(3);
  midLeftX = readIntFromEEPROM(5);
//Left Y
  minLeftY = readIntFromEEPROM(7);
  maxLeftY = readIntFromEEPROM(9);
  midLeftY = readIntFromEEPROM(11);
//Right Y
  minRightY = readIntFromEEPROM(13);
  maxRightY = readIntFromEEPROM(15);
  midRightY = readIntFromEEPROM(17);
// Right X
  minRightX = readIntFromEEPROM(19);
  maxRightX = readIntFromEEPROM(21);
  midRightX = readIntFromEEPROM(23);
}

void writeJoystickConfig(){ //Store joystick calibration in EEPROM
//Left X
  writeIntIntoEEPROM(1, minLeftX);
  writeIntIntoEEPROM(3, maxLeftX);
  writeIntIntoEEPROM(5, midLeftX);
//Left Y
  writeIntIntoEEPROM(7, minLeftY);
  writeIntIntoEEPROM(9, maxLeftY);
  writeIntIntoEEPROM(11, midLeftY);
//Right Y
  writeIntIntoEEPROM(13, minRightY);
  writeIntIntoEEPROM(15, maxRightY);
  writeIntIntoEEPROM(17, midRightY);
// Right X
  writeIntIntoEEPROM(19, minRightX);
  writeIntIntoEEPROM(21, maxRightX);
  writeIntIntoEEPROM(23, midRightX);
}

int readJoystick(int joystickPin, boolean invertOutput){ //Reads raw joystick values and inverts if required
  int var = analogRead(joystickPin);
  if(invertOutput){
    var = 1023 - var;
    return var;
  } else {
    return var;
  }
}

void joystickCalibration(){ //Very rough at the moment but it works. Read usage instructions at top of page.
  buttonRead();
  if(calibrationStep == 1){
    if(lastButtonState[1] == 1){
      RXLED1;
      delay(100);
      RXLED0;
      midLeftX = readJoystick(leftJoyX, invertLeftX);
      midLeftY = readJoystick(leftJoyY, invertLeftY);
      midRightX = readJoystick(rightJoyX, invertRightX);
      midRightY = readJoystick(rightJoyY, invertRightY);
      calibrationStep = 2;
    }
  } else if(calibrationStep == 2){
      RXLED1;
      delay(100);
      RXLED0;
      minLeftX = midLeftX;
      minLeftY = midLeftY;
      maxLeftX = 0;
      maxLeftY = 0;
      minRightX = midRightX;
      minRightY = midRightY;
      maxRightX = 0;
      maxRightY = 0;
      calibrationStep = 3;
      delay(500);
  } else if(calibrationStep == 3){
    int var = readJoystick(leftJoyX, invertLeftX);
    if(var > maxLeftX) maxLeftX = var;
    if(var < minLeftX) minLeftX = var;
    var = readJoystick(leftJoyY, invertLeftY);
    if(var > maxLeftY) maxLeftY = var;
    if(var < minLeftY) minLeftY = var;
    var = readJoystick(rightJoyX, invertRightX);
    if(var > maxRightX) maxRightX = var;
    if(var < minRightX) minRightX = var;
    var = readJoystick(rightJoyY, invertRightY);
    if(var > maxRightY) maxRightY = var;
    if(var < minRightY) minRightY = var;
    buttonRead();
    if(lastButtonState[1] == 1){ //Complete Calibration
      RXLED1;
      delay(100);
      RXLED0;
      delay(200);
      writeJoystickConfig(); //Update EEPROM
      rebuildLUTs();
      calibrationStep = 1;
      calibrationMode = false;
    }
  }
}

void joystickBuildLUT(byte output[350], int minIn, int midIn, int maxIn, int earlyStop, int deadBand){ //This function builds a lookup table for the given axis.
  //Shift all joystick values to a base of zero. All values are halved due to ram limitations on the 32u4.
  int shiftedMin = 0;
  int shiftedMid = (midIn - minIn) /2;
  int shiftedMax = (maxIn - minIn) /2;
  int temp;
  
  for(int i = 0; i < 350; i++){
    if(i < shiftedMid){
      if(i > shiftedMin + earlyStop){
        temp = map(i, shiftedMin, shiftedMid - deadBand, 0, 127);
      } else {
        temp = 0;
      }
    } else {
      if(i < shiftedMax - earlyStop){
        temp = map(i, shiftedMid + deadBand, shiftedMax, 127, 254);
      } else {
        temp = 254;
      }
    }
    if(i < shiftedMid + deadBand && i > shiftedMid - deadBand){
      temp = 127;
    }
    output[i] = temp;
  }
}

//OLD
/*void joystickBuildLUT(byte output[350], int minIn, int midIn, int maxIn, int earlyStop, int deadBand){ //This function builds a lookup table for the given axis.
  //Shift all joystick values to a base of zero. All values are halved due to ram limitations on the 32u4.
  int shiftedMin = 0;
  int shiftedMid = (midIn - minIn) /2;
  int shiftedMax = (maxIn - minIn) /2;
  int temp;
  
  for(int i = 0; i < 350; i++){
    if(i < shiftedMid){
      temp = map(i, shiftedMin + earlyStop, shiftedMid - deadBand, 0, 127);
      if(temp < 0){
        temp = 0;
      } else if(temp > 254){
        temp = 254;
      }
    } else {
      temp = map(i, shiftedMid + deadBand, shiftedMax - earlyStop, 127, 254);
      if(temp < 0){
        temp = 0;
      } else if(temp > 254){
        temp = 254;
      }
    }
    if(i < shiftedMid + deadBand && i > shiftedMid - deadBand){
      temp = 127;
    }
    output[i] = temp;
  }
}*/

void joystickInput(){
  int var = 0;
  var = readJoystick(rightJoyY, invertRightY);
  var = (var - minRightY) / 2;
  Joystick.setRxAxis(rightYLUT[var]);

  var = readJoystick(rightJoyX, invertRightX);
  var = (var - minRightX) / 2;
  Joystick.setZAxis(rightXLUT[var]);

  var = readJoystick(leftJoyY, invertLeftY);
  var = (var - minLeftY) / 2;
  Joystick.setYAxis(leftYLUT[var]);

  var = readJoystick(leftJoyX, invertLeftX);
  var = (var - minLeftX) / 2;
  Joystick.setXAxis(leftXLUT[var]);
}

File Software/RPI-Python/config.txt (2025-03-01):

# For more options and information see
# http://rptl.io/configtxt
# Some settings may impact device functionality. See link above for details

# Uncomment some or all of these to enable the optional hardware interfaces
dtparam=i2c_arm=on
#dtparam=i2s=on
dtparam=spi=on
dtparam=i2c13=on

# Switch to external antenna.
dtparam=ant2

# Enable audio (loads snd_bcm2835)
dtparam=audio=on

# Additional overlays and parameters are documented
# /boot/firmware/overlays/README

# Automatically load overlays for detected cameras
camera_auto_detect=1

# Automatically load overlays for detected DSI displays
display_auto_detect=1

# Automatically load initramfs files, if found
auto_initramfs=1

# Enable DRM VC4 V3D driver
dtoverlay=vc4-kms-v3d
max_framebuffers=2

# Don't have the firmware create an initial video= setting in cmdline.txt.
# Use the kernel's default instead.
disable_fw_kms_setup=1

# Run in 64-bit mode
arm_64bit=1

# Disable compensation for displays with overscan
disable_overscan=1

# Run as fast as firmware / board allows
arm_boost=1

[cm4]
# Enable host mode on the 2711 built-in XHCI USB controller.
# This line should be removed if the legacy DWC2 controller is required
# (e.g. for USB device mode) or if USB support is not required.
otg_mode=1

[cm5]
dtoverlay=dwc2,dr_mode=host

[all]
dtoverlay=gpio-poweroff,gpiopin=6,active_low=0,timeout_ms=10000,active_delay_ms=10000
dtparam=pciex1_gen=3

# Tell the DVFS algorithm to increase voltage by this amount (in µV; default 0).
over_voltage_delta=10000

# Set the Arm A76 core frequency (in MHz; default 2400).
arm_freq=2600

# Set the VideoCore VII core frequency (in MHz; default 800).
gpu_freq=900

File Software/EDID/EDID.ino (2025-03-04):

/*Credit: Adafruit: https://learn.adafruit.com/adafruit-tfp401-hdmi-slash-dvi-decoder-to-40-pin-ttl-display/editing-the-edid*/

#include <Wire.h> //I2C library


/* 480x272 @ 25mhz

uint8_t PROGMEM eepromdat[128] = {
0x00, 0xFF, 0xFF, 0xFF, 0xFF, 0xFF, 0xFF, 0x00, 0x04, 0x81, 0x43, 0x00, 0x01, 0x00, 0x00, 0x00, 
0x0C, 0x17, 0x01, 0x03, 0x81, 0x0A, 0x06, 0x78, 0x8A, 0xA5, 0x8E, 0xA6, 0x54, 0x4A, 0x9C, 0x26, 
0x12, 0x45, 0x46, 0x00, 0x00, 0x00, 0x01, 0x01, 0x01, 0x01, 0x01, 0x01, 0x01, 0x01, 0x01, 0x01, 
0x01, 0x01, 0x01, 0x01, 0x01, 0x01, 0xC4, 0x09, 0xE0, 0x33, 0x10, 0x10, 0x14, 0x10, 0x08, 0x05, 
0x4A, 0x00, 0x5F, 0x36, 0x00, 0x00, 0x00, 0x18, 0x00, 0x00, 0x00, 0xFC, 0x00, 0x41, 0x44, 0x41, 
0x46, 0x52, 0x55, 0x49, 0x54, 0x20, 0x34, 0x33, 0x20, 0x20, 0x00, 0x00, 0x00, 0x10, 0x00, 0x00, 
0x00, 0x00, 0x00, 0x00, 0x00, 0x00, 0x00, 0x00, 0x00, 0x00, 0x00, 0x00, 0x00, 0x00, 0x00, 0x10, 
0x00, 0x00, 0x00, 0x00, 0x00, 0x00, 0x00, 0x00, 0x00, 0x00, 0x00, 0x00, 0x00, 0x00, 0x00, 0x42
};
*/
/* Adafruit breakout @ 800x480 ! */ 
const uint8_t PROGMEM eepromdat[128] = {
0x00, 0xFF, 0xFF, 0xFF, 0xFF, 0xFF, 0xFF, 0x00, 0x04, 0x81, 0x04, 0x00, 0x01, 0x00, 0x00, 0x00,
0x01, 0x11, 0x01, 0x03, 0x80, 0x0F, 0x0A, 0x00, 0x0A, 0x00, 0x00, 0x00, 0x00, 0x00, 0x00, 0x00,
0x00, 0x00, 0x00, 0x00, 0x00, 0x00, 0x01, 0x01, 0x01, 0x01, 0x01, 0x01, 0x01, 0x01, 0x01, 0x01,
0x01, 0x01, 0x01, 0x01, 0x01, 0x01, 0x80, 0x0C, 0x20, 0x80, 0x30, 0xE0, 0x2D, 0x10, 0x28, 0x30,
0xD3, 0x00, 0x6C, 0x44, 0x00, 0x00, 0x00, 0x18, 0x00, 0x00, 0x00, 0x10, 0x00, 0x00, 0x00, 0x00,
0x00, 0x00, 0x00, 0x00, 0x00, 0x00, 0x00, 0x00, 0x00, 0x00, 0x00, 0x00, 0x00, 0x10, 0x00, 0x00,
0x00, 0x00, 0x00, 0x00, 0x00, 0x00, 0x00, 0x00, 0x00, 0x00, 0x00, 0x00, 0x00, 0x00, 0x00, 0x10,
0x00, 0x00, 0x00, 0x00, 0x00, 0x00, 0x00, 0x00, 0x00, 0x00, 0x00, 0x00, 0x00, 0x00, 0x00, 0x17,
};

// I2C eeprom dumper
byte i2c_eeprom_read_byte(uint8_t deviceaddress, uint16_t eeaddress );

#define EEPROMSIZE 256UL  // 0.5 Kb
#define ADDRESS_SIZE 8

byte i2c_eeprom_read_byte(uint8_t deviceaddress, uint16_t eeaddress ) {
    byte rdata = 0xFF;
#if (ADDRESS_SIZE == 16)
    Wire.beginTransmission(deviceaddress);
    Wire.write((eeaddress >> 8)); // MSB
#else
    //deviceaddress |= (eeaddress >> 8);
    Wire.beginTransmission(deviceaddress); // MSB
#endif
    Wire.write(eeaddress); // LSB
    Wire.endTransmission();
    Wire.requestFrom(deviceaddress, (uint8_t)1);
    while (!Wire.available()); 
    rdata = Wire.read();
    return rdata;
}

void i2c_eeprom_write_byte(uint8_t deviceaddress, uint16_t eeaddress, byte data ) {
#if (ADDRESS_SIZE == 16)
    Wire.beginTransmission(deviceaddress);
    Wire.write((eeaddress >> 8)); // MSB
#else
    //deviceaddress |= (eeaddress >> 8);
    Wire.beginTransmission(deviceaddress); // MSB
#endif
    Wire.write((byte)eeaddress); // LSB
    Wire.write((byte)data);
    Wire.endTransmission();
}
  

void setup() {
  Wire.begin(); // initialise the connection
  Serial.begin(9600);
  Serial.println(F("EEPROM WRITER"));
  Serial.print(F("EEPROM data size: "));
  Serial.println(sizeof(eepromdat));
  Serial.println(F("Hit any key & return to start"));
  while (!Serial.available());
  byte b;
  Serial.println("Starting");
  for (uint16_t addr = 0; addr < EEPROMSIZE; addr++) {
    if (addr < sizeof(eepromdat)) {
      b = pgm_read_byte(eepromdat+addr);
    } else {
      b = 0xFF;
    }
     i2c_eeprom_write_byte(0x50, addr, b);
     delay(5);
     if ((addr % 32) == 0)
       Serial.println();
     Serial.print("0x");
     if (b < 0x10) Serial.print('0');
     Serial.print(b, HEX); //print content to serial port
     Serial.print(", ");
  }
  Serial.println("\n\r========\n\rFinished!");
  for (uint16_t addr = 0; addr < EEPROMSIZE; addr++) {
    if (addr < sizeof(eepromdat)) {
      b = pgm_read_byte(eepromdat+addr);
    } else {
      b = 0xFF;
    }
    uint8_t d =  i2c_eeprom_read_byte(0x50, addr);
    if ((addr % 32) == 0)
      Serial.println();
    Serial.print("0x");
    if (d < 0x10) Serial.print('0');
    Serial.print(d, HEX); //print content to serial port
    Serial.print(", ");

    if (b != d) {
       Serial.print(F("verification failed at 0x")); Serial.println(addr);
       while (1);
     }
  }
  Serial.println(F("\n\r\n\rVerified!"));
}

void loop() {
}

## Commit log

2025-03-02 Added board step files
    [Battery_Flex.step, Left_Flex.step, Right_Flex.step]
2025-03-02 Added multi-board project files
2025-03-04 Updated schematics
2025-03-04 Updated CAD file
    [Back Cover.step]
2025-03-04 Restructured Folders
    [Ant_Cover.step, Audio.SchDoc, Back Cover.step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]
2025-03-04 Restructured Repository
    [Acrylic_Bezel.step, Ant_Cover.step, Back_Cover.step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]
2025-03-04 Added and renamed images
    [Ant_Cover.step, Audio.SchDoc, Battery_FPC.step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]
2025-03-04 Updated schematic design files
    [Audio.SchDoc, Display.SchDoc, Module A IO.SchDoc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]
2025-03-05 Updated Power schematic
    [Power.SchDoc]
2025-03-08 Added Bill of Materials
    [Back_Cover.step, Fan_CN_Cover.step, RP5-Console_BOM.xlsx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]
2025-03-08 Updated Bill of Materials
    [RP5-Console_BOM.xlsx]
